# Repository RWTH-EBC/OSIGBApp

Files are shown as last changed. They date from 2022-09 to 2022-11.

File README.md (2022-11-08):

# OSIGBApp
Open-Source Internet of Things (IoT) Gateways for Building Automation Applications

This repository will be populated in course of a journal publication (see publications section down below).

<!-- openocd -f board/esp32-wrover-kit-3.3v.cfg -->

## General

The IoT gateways are designed to operate as an interface for legacy components in building automation systems and IoT-based applications, e. g. connecting to cloud services via IoT protocols communication like MQTT. 

To this end, this repository contains the relevant [schematics and PCB design](https://github.com/RWTH-EBC/OSIGBApp/tree/main/Schematics) to obtain the interfacing hardware allowing to digitize and convert signals from sensors or to actuators. 
Here, the following signals are supported:
- Analog communication (0-10 V, 0-20 mA)
- Resistive measurements of passive RTD-probes (2,3,4-wire)
- Digital communication via RS-485/EIA-485 (for instance used in serial Modbus RTU or BACnet MS/TP communication)

Core component of the gateways is the ESP32 microcontroller.
Hence, the firmware was developed using the Espressif IoT Development Framework [ESP-IDF](https://github.com/espressif/esp-idf), which is the official development framework provided by the manufacturer for the [ESP32](https://espressif.com/en/products/hardware/esp32/overview) chip.
Accordingly, the developed [firmware](https://github.com/RWTH-EBC/OSIGBApp/tree/main/Firmware) is provided as well in this repository. 
In order to ease use and operation of the gateways, we further provide a [documentation](https://github.com/RWTH-EBC/OSIGBApp/tree/main/Documentation). 
Finally, a [performance analysis](https://github.com/RWTH-EBC/OSIGBApp/tree/main/PerformanceAnalysis) has been conducted comparing the measurement performance with a conversion via a PLC.

## Documentation:
- The user Manual "how to operate the gateways" can be found [here](Documentation/manual.pdf). 
- For using the software, [ESP-IDF](https://github.com/espressif/esp-idf) is needed. We also recommend to use [VScode](https://code.visualstudio.com/) with the ESP-IDF extension for programming.
- Furthermore, tips for using the Menuconfig with this software can be found in the Wiki of the repository.
- All functions in the code are commented and a documentation is generated with [Doxygen](https://github.com/doxygen/doxygen). The result can be found in the [DOC folder](https://github.com/RWTH-EBC/OSIGBApp/tree/main/Firmware/doc). You have to clone the repository and open doc/doxygen/html/index.html to view the complete documentation.

- Documentation on how to build the Aio Configurator webpage can be found here: [AIO Configurator](Firmware/doc/aio_configurator.md)
  - The IoT-AIO Configurator is a web page that uses HTML forms to configure the IoT Wireless Adapter.
    The source code and documentation can be obtained here:
      - [Configurator Request](Firmware/doc/markdown/aio_configurator_request.html)
      - [Configurator Response](Firmware/doc/markdown/aio_configurator_response.html)
     
- Further developement Ideas, by Carlo Guarnieri can be found here: [Developments](Firmware/doc/developments.md)

## Terms of use
All content provided in this repository is released under the [MIT License](https://github.com/RWTH-EBC/OSIGBApp/blob/main/LICENSE). 
If any of the content provided is used, please give credit by referencing the related publication, as decribed in the subsequent section.

## Publications and referencing
<!--The IoT-Gateways have been developed in several research projects between 2018 and 2021. A core development for the current state has been conducted during the Master Thesis of Kai Droste in 2020. -->
We kindly ask all publicly disseminated projects employing components of the IoT gateways to cite the following paper:

<!--  - Kai Droste "[Development of a cloud controlled building automation and comparison with the current state of the art](https://git-ce.rwth-aachen.de/ebc/projects/ebc0449_bmwi_nextgenbat_ga/iot-development/iot-development.dissemination/theses/development-of-a-cloud-controlled-building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)", 2020 Masterthesis   -->
- **Schraven, Markus Hans, Kai Droste, Carlo Guarnieri Calò Carducci, Dirk Müller, and Antonello Monti. 2022. "Open-Source Internet of Things Gateways for Building Automation Applications" Journal of Sensor and Actuator Networks 11, no. 4: 74. https://doi.org/10.3390/jsan11040074**

Previous development stages are documented in:
- M.H. Schraven, C. Guarnieri Calò Carducci, M.A. Baranski, D. Mueller, A. Monti, “Designing a Development Board for Research on IoT Appli-cations in Building Automation Systems,” 36th International Symposiumon  Automation  and  Robotics  in  Construction  (ISARC  2019),  Banff,Canada, 2019, pp. 82-90, [DOI: 10.22260/ISARC2019/0012](https://doi.org/10.22260/ISARC2019/0012)
- C. Guarnieri Calò Carducci, A. Monti, M. H. Schraven, M. Schumacher and D. Mueller, “Enabling ESP32-based IoT Applications in Building Automation Systems,” 2019 II Workshop on Metrology for Industry 4.0 and IoT (MetroInd4.0&IoT), Naples, Italy, 2019, pp. 306-311, [DOI: 10.1109/METROI4.2019.8792852](https://doi.org/10.1109/METROI4.2019.8792852)

# Further software related to IoT-AIO

## IoT-AIO Configurator

# Contact
EONERC EBC Logo (http://www.ebc.eonerc.rwth-aachen.de)

- [Kai Droste](mailto:kai.droste@eonerc.rwth-aachen.de)
- [Markus Schraven](mailto:mschrave@eonerc.rwth-aachen.de)
- [Carlo Guarnieri](mailto:cguarnieri@eonerc.rwth-aachen.de)

[EON Energy Research Center (EONERC)](http://www.eonerc.rwth-aachen.de)  
[Institute for Automation of Complex Power Systems (ACS)](http://www.acs.eonerc.rwth-aachen.de)  
[RWTH University Aachen, Germany](http://www.rwth-aachen.de)

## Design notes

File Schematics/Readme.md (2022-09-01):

# Schematics

This folder contains the schematics of the three gateways. The schematics are drawn with the Open-Source software KiCAD.

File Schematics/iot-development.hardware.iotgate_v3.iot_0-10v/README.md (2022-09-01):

# iot analog io interface

This repository entails the specifications and PCB design of a gateway communicating with 0-10 V and 0-20 mA devices. 

**Specifications:**
*  Case:
    * [Datasheet](Datasheet/M-2K-12_V1.pdf)
    * outer dimensions: 85 x 85 x 37 mm 
    * inner dimensions: 73 x 73 x 25 mm
    * [PCB-Measurements:](Datasheet/Junction-Box-PCB.pdf) 75 x 40 x 1.6 mm 
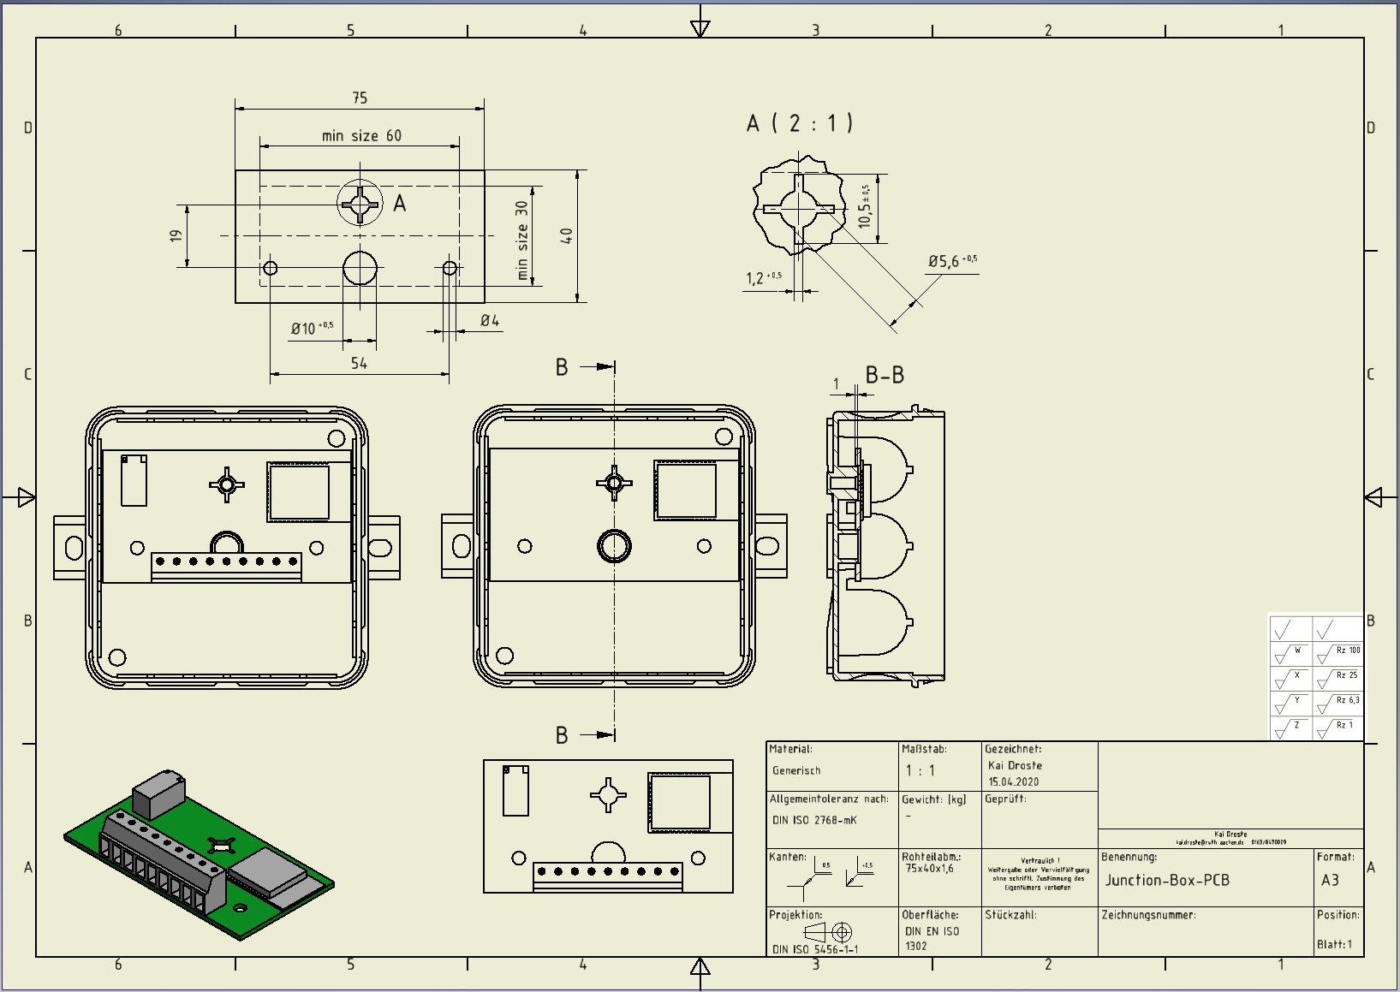
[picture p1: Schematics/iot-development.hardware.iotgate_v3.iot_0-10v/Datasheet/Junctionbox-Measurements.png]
    

*  Components: 
    * ESP32-WROOM-32D(4MB)
    * Header Pins for flashing bridge [ESP-Prog](https://github.com/espressif/esp-iot-solution/blob/master/documents/evaluation_boards/ESP-Prog_guide_en.md)
    * Reset Button (EN)
    * Status / Debugging LED
    * DC-DC Buck Converter: VXO7805-500-M-TR [Mouser-Link](https://eu.mouser.com/ProductDetail/CUI-Inc/VXO7805-500-M-TR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)  
    * LDO 5V-3.3V: REG1117-3.3/2K5 [Mouser-Link](https://eu.mouser.com/ProductDetail/Texas-Instruments/REG1117-33-2K5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)
       
    * ADC/DAC as external circuit 
        * ADC
            * 0-10 V
            * resolution 10 bit 
    * XTR111 Voltage to current Converter [Mouser-Link](https://www.mouser.de/ProductDetail/Texas-Instruments/XTR111AIDGQR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)
    * header with jumper to set current or voltage mode
*  Additional components:
    * Double relay switch
    * Connector: 9 Position Screw Terminal 
        * [TB001-500-09BE](https://www.mouser.de/ProductDetailCUI-Devices/TB001-500-09BEqs=sGAEpiMZZMvPvGwLNS671%2FDanv8Jav06pFwBruE7rNiHV5dcUdCoOg%3D3D)
        * [Datasheet](Datasheet/tb001-500-1550615.pdf)
    * 2x6 pin header: M20-9760346 [Mouser-Link](https://eu.mouser.com/ProductDetail/Harwin/M20-9760346?qs=sGAEpiMZZMs%252BGHln7q6pmzlZUuX%2F53qjFNOh3aK0cf8%3D)

*  IOs:
1. 24 VDC (input, supply gateway)
2. GND (input, supply gateway)
3. 24 VDC (output, supply sensor/actuator device)
4. GND (output, sensor/actuator device)
5. 0-10 VDC / 0-20 mA (switched by jumper) (feedback signal from sensor/actuator device)
6. 0-10 VDC / 0-20 mA (switched by jumper) (feedback signal from sensor/actuator device forwarding to PLC)
7. 0-10 VDC / 0-20 mA (switched by jumper) (set point signal to sensor/actuator device forwarding from PLC)
8. 0-10 VDC / 0-20 mA (switched by jumper) (set point signal to sensor/actuator device)
9. 24 VDC (input for relay switch from PLC)

## TODO:
- [x] Housing
	- [x] Measurements
	- [x] Mounting Holes

## Example board layout:

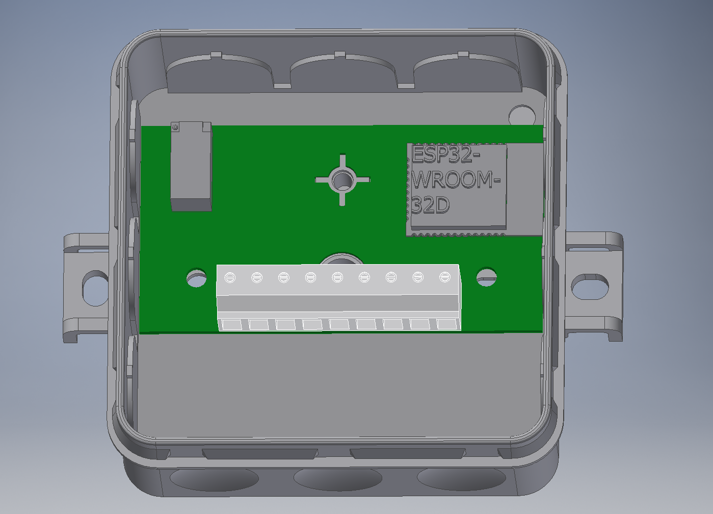
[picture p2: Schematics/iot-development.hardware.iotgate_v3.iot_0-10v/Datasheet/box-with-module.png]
box with module

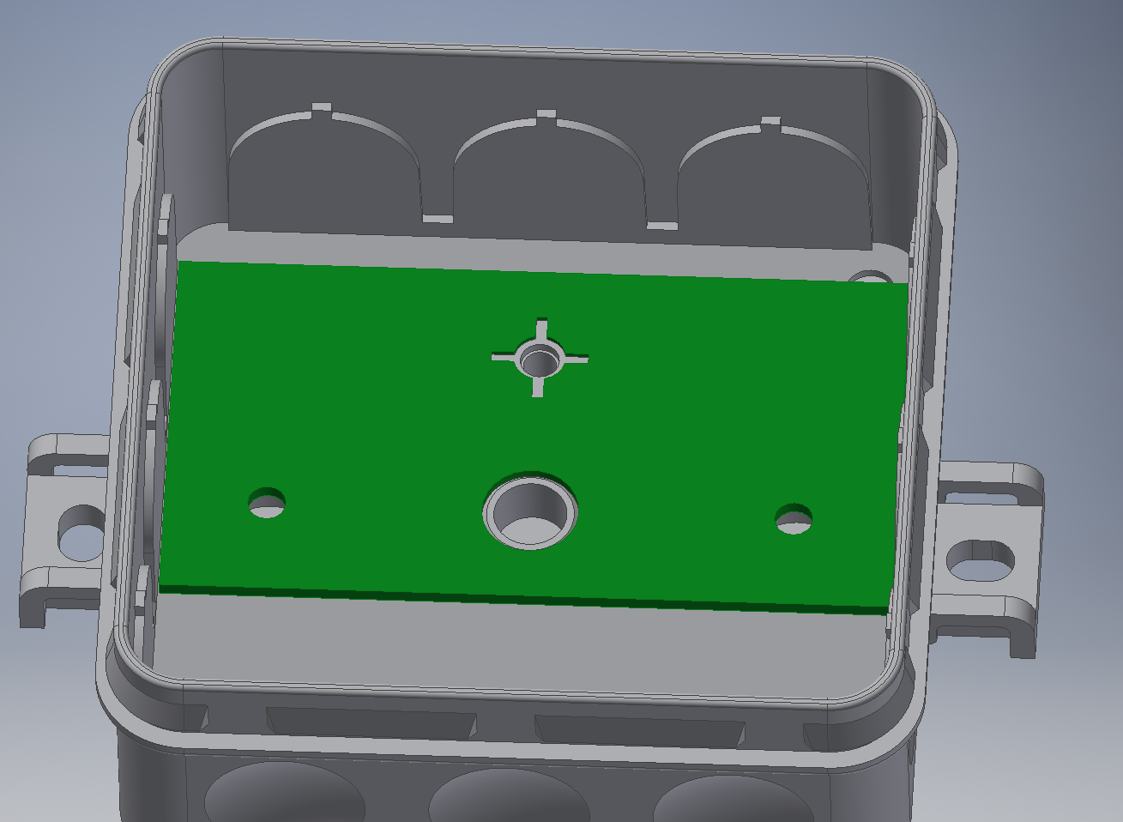
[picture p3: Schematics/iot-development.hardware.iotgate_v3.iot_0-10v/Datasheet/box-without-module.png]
box without module


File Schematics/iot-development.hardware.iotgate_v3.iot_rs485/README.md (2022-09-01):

# iot_rs485

This repository entails the specifications and PCB design of a gateway communicating with devices via Modbus RTU or BACnet MS/TP.

**Specifications:**
*  Battery: None
*  Case:
    * [Datasheet](Datasheet/M-2K-12_V1.pdf)
    * outer dimensions: 85 x 85 x 37 mm 
    * inner dimensions: 73 x 73 x 25 mm
    * [PCB-Measurements:](Datasheet/Junction-Box-PCB.pdf) 75 x 40 x 1.6 mm 
    

*  Components: 
    * ESP32-WROOM-32D(16MB)
    * Header Pins for flashing bridge [ESP-Prog](https://github.com/espressif/esp-iot-solution/blob/master/documents/evaluation_boards/ESP-Prog_guide_en.md)
    * UART TTL to RS485 converter (Maybe BACnet needs an own gateway with a card reader? Needs to be tested)
        * Modbus-RTU
        * BACnet MS/TP
*  Additional components:
    * Double relay switch
    * Connector: 9 Position Screw Terminal 
        * [TB001-500-09BE](https://www.mouser.de/ProductDetail/CUI-Devices/TB001-500-09BE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)
        * [Datasheet](Datasheet/tb001-500-1550615.pdf)

*  IOs:
1. 24 VDC (input, supply gateway)
2. GND (input, supply gateway)
3. 24 VDC (output, supply sensor/actuator device)
4. GND (output, supply sensor/actuator device)
5. M+ (Bus signal from sensor/actuator device)
6. M- (Bus signal from sensor/actuator device)
7. M+ (Bus signal to sensor/actuator device forwarding from PLC)
8. M- (Bus signal to sensor/actuator device forwarding from PLC)
9. 24 VDC (input for relay switch from PLC)

## TODO:

- [ ] Testing BACnet.

## Example board layout:

box with module
box without module

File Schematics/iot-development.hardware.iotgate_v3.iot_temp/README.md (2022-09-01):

# iot_temp

This repository entails the specifications and PCB design of a gateway communicating with temperature sensors.

**Specifications:**
*  Battery: LiFePo4 18650 cell [lipopower.de](https://shop.lipopower.de/A123-Systems-APR18650M1A-1100mAh)
    * Battery holder: [Datasheet](Datasheet/Keystone_01142020_1042.pdf)
*  Case dimensions: 120 x 75 x 36 mm 
    *  Case Datasheet: [Spelsberg 2K-16](Datasheet/M-346-916-01_V1.pdf)
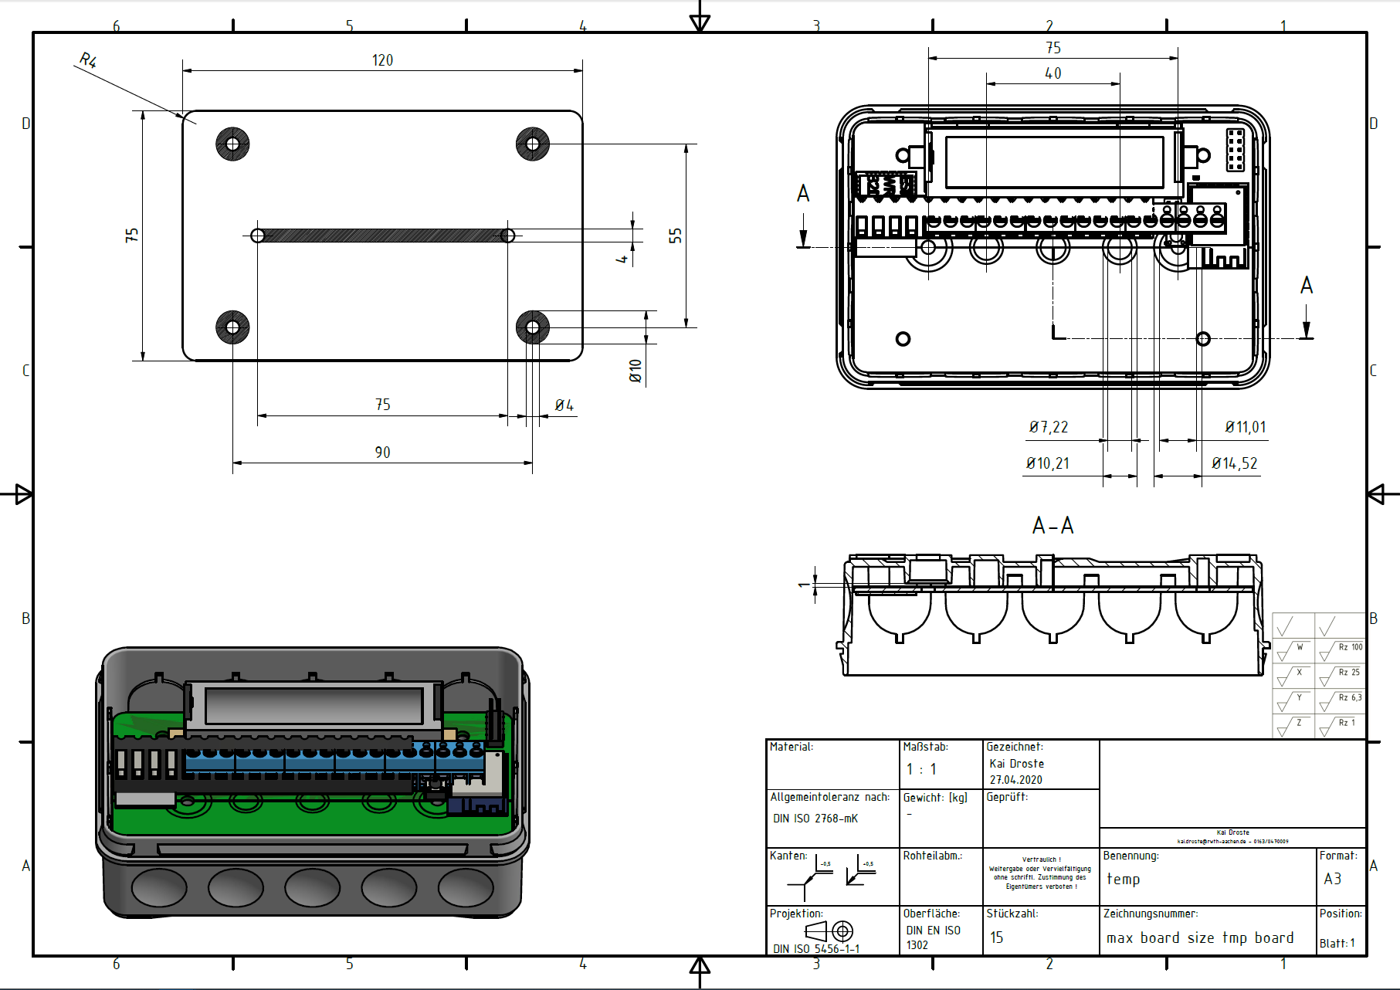
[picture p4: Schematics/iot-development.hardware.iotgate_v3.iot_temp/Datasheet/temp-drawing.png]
Temp-drawing

[Drawing](Datasheet\temp-drawing.pdf)

* ESP32-WROOM-32D
* Header Pins for flashing bridge 
    * [ESP-Prog](https://github.comespressif/esp-iot-solution/blob/master/documentsevaluation_boards/ESP-Prog_guide_en.md)
* Reset Button (EN)
* 2x MAX31865 for 2 RTD-Elements
* TS3A44159PWR Multiplexer for switching between PLC and ESP32
    * [Mouser-Link](https://www.mouser.de/ProductDetail/Texas-Instruments/TS3A44159PWR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)
* Terminal block 18 TB004-508-18BE 
    * [Mouser-Link](https://www.mouser.de/ProductDetail/CUI-Devices/TB004-508-18BE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)

**IOs:**
1. Lead 1 RTD 1 (from RTD to Gateway) 
2. Lead 2 RTD 1 (from RTD to Gateway)
3. Lead 3 RTD 1 (from RTD to Gateway)
4. Lead 4 RTD 1 (from RTD to Gateway)
5. Lead 1 RTD 2 (from RTD to Gateway)
6. Lead 2 RTD 2 (from RTD to Gateway)
7. Lead 3 RTD 2 (from RTD to Gateway)
8. Lead 4 RTD 2 (from RTD to Gateway)
9. Lead 1 RTD 1 (from RTD forwarding to PLC) 
10. Lead 2 RTD 1 (from RTD forwarding to PLC)
11. Lead 3 RTD 1 (from RTD forwarding to PLC)
12. Lead 4 RTD 1 (from RTD forwarding to PLC)
13. Lead 1 RTD 2 (from RTD forwarding to PLC)
14. Lead 2 RTD 2 (from RTD forwarding to PLC)
15. Lead 3 RTD 2 (from RTD forwarding to PLC)
16. Lead 4 RTD 2 (from RTD forwarding to PLC)
17. GND (input for relais switch from PLC)
18. 24 VDC (input for relais switch from PLC)

## TODO:
- [x] Housing for Battery and Board
	- [x] Measurements
	- [x] Mounting Holes

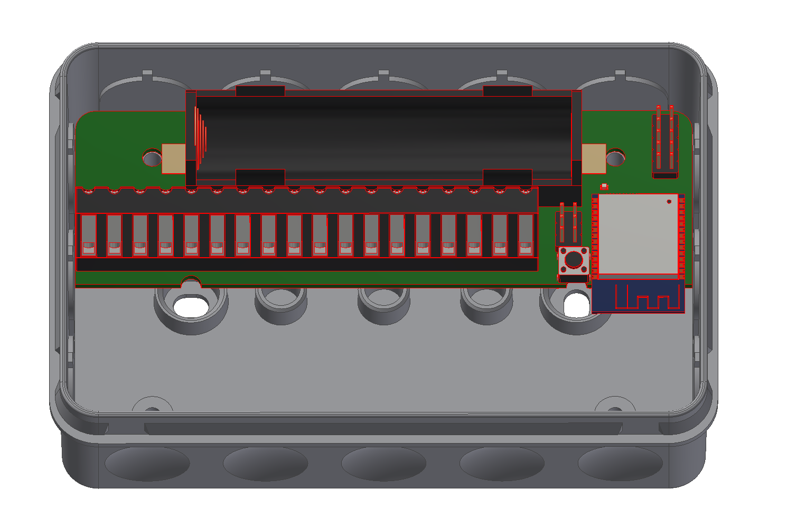
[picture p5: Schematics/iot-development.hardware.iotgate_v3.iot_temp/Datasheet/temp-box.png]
Rendering


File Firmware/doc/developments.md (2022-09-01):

# Possible developments

- DNS Captive Portal feature for autoloading the configurator page upon new connection
    - [DNSServer [Arduino-ESP32]](https://github.com/espressif/arduino-esp32/blob/master/libraries/DNSServer/examples/CaptivePortal/CaptivePortal.ino)
    - [mDNS [ESP-IDF]](https://github.com/espressif/esp-idf/tree/master/examples/protocols/mdns)

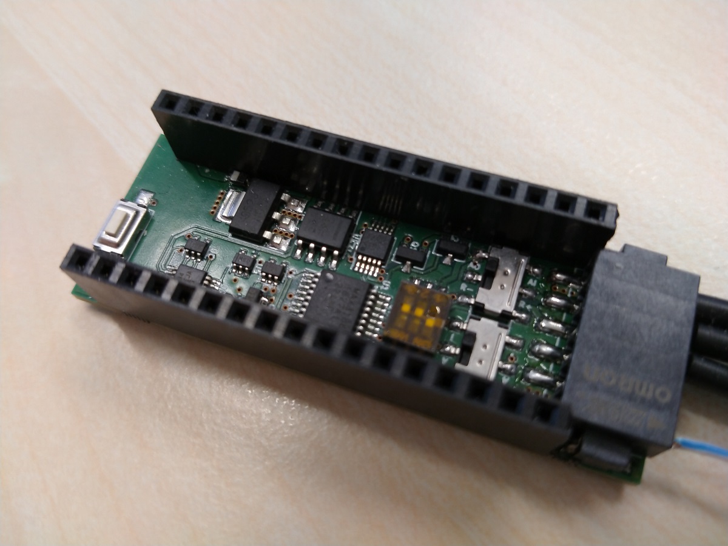
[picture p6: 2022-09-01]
Firmware/assets/image.jpg

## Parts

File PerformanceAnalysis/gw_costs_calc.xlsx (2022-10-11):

Gateway costs
 | Analog |  | Digital |  | Temperature
PCB Manufacturing | 223.25 € | 3.92 € | 182.02 € | 4.79 € | 244.86 € | 11.13 €
Assembly | 663.48 € | 11.64 € | 396.34 € | 10.43 € | 378.84 € | 17.22 €
Components | 1169.07 € | 20.51 € | 625.10 € | 16.45 € | 549.34 € | 24.97 €
Summe | 2055.80 € | 36.07 € | 1203.46 € | 31.67 € | 1173.04 € | 53.32 €
Anzahl | 57 |  | 38 |  | 22

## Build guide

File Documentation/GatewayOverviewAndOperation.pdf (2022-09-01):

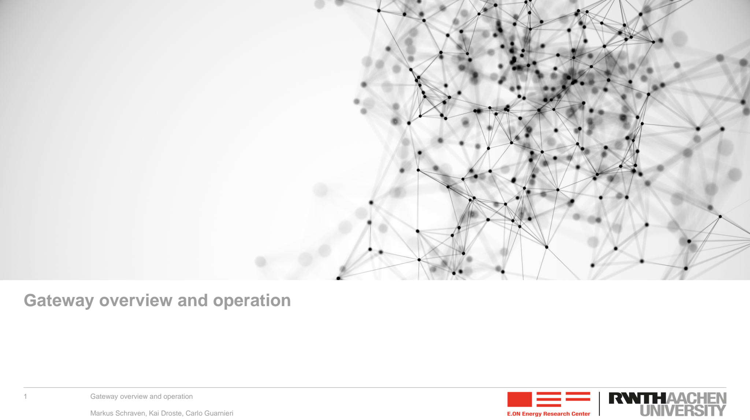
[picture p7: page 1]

Gateway overview and operation

Markus Schraven, Kai Droste, Carlo Guarnieri

## Gateway overview and operation

### Content

### ■ 1. General information, gateway properties and possible use-cases

### ■ 2. Operators instructions I – Configuration

### ■ 3. Operators instructions II – Inital setup / Flashing the firmware

### ■ 4. Developers instructions – Development / Adjusting the firmware

# General information

### Microcontroller

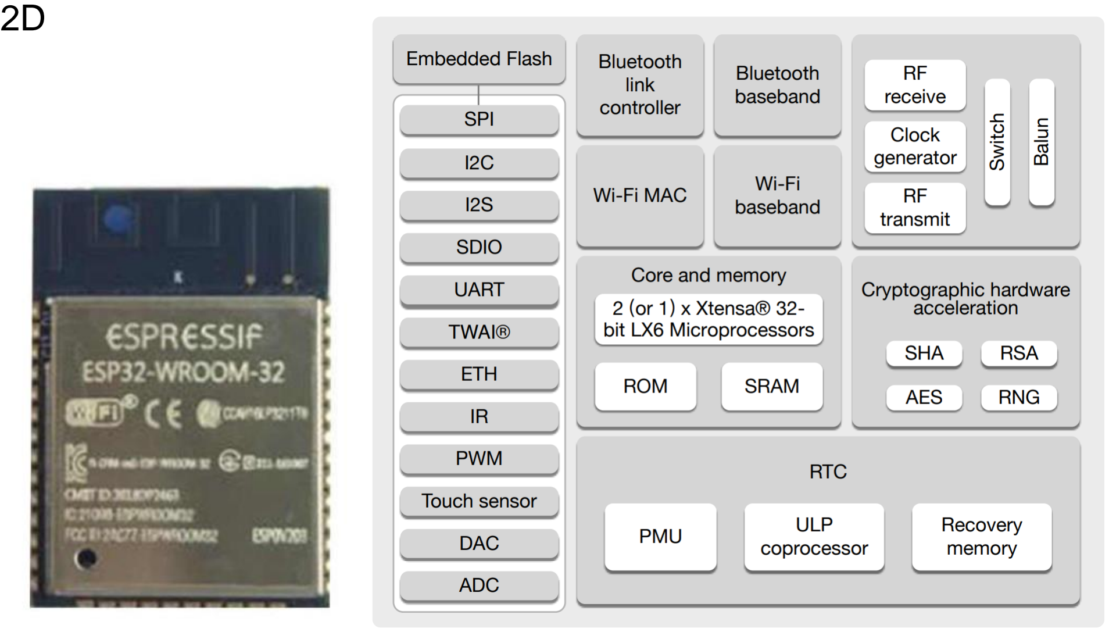
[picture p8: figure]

■ Core component is an ESP32-WROOM32D

≡ 32-bit, dual-core 40 MHz
≡ 16MB flash storage
≡ 34 programmable GPIOS
≡ 2,4 GHz WiFi
≡ Bluetooth, Bluetooth low energy ■ Programming languages

≡ C (ESP-IDF)
≡ C++ (Arduino IDE)
≡ Micropython

Data sheet: https://www.espressif.com/sites/default/files/documentation/esp32-wroom-32d_esp32-wroom-32u_datasheet_en.pdf

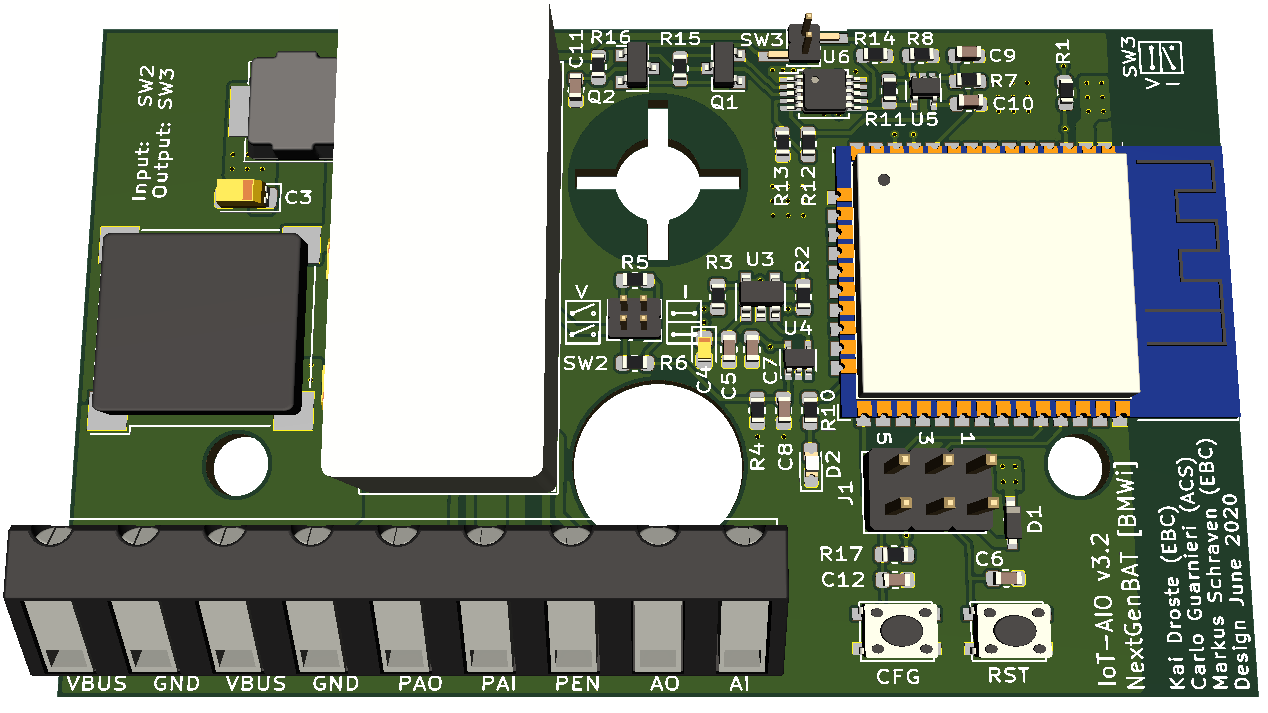
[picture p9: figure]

Analog
■ 0(2) – 10 V
■ 0(4) – 20 mA

■ 1x Input, 1x Output
(single-ended)
■ MCP3021, XTR111

Temperature
■ RTD-probe

≡ 2,3,4 wires
■ Optional Battery operated (LiFePO4, 18650 cells)
■ 24 VDC add-on supply
■ 2 RTD-probes
■ MAX31865

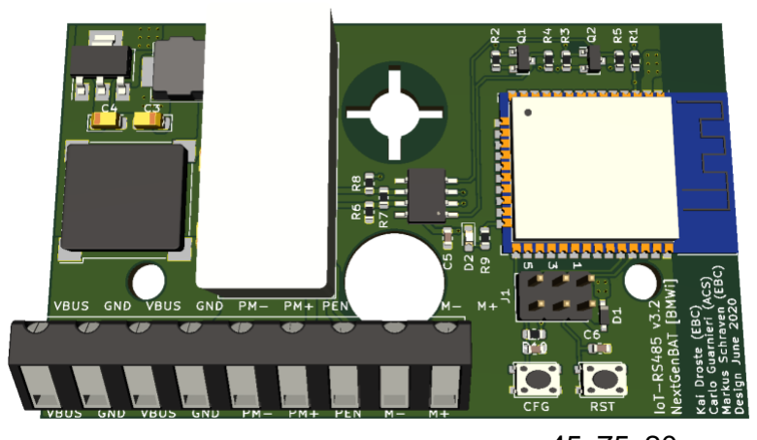
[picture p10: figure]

Digital
■ RS485
■ Modbus RTU
■ (BACnet MS/TP, not
yet implemented)
■ Communication with one
field device (Software)
■ MAX13487
Price: 36,07 €/pcs. | 31,67 €/pcs. | 53,32 €/pcs.

45x120x17 mm
45x75x20 mm | 45x75x20 mm

### Analog Gateway

■ Relay
■ Switching between
internal and external
signal path (“to PLC”),
compare slide 16

Pins labeled with „Not in use“ are used for the switching mechanism. More details can be found in chapter 2 of the instruction manual or slide 16 in this presentation.

### Digital Gateway

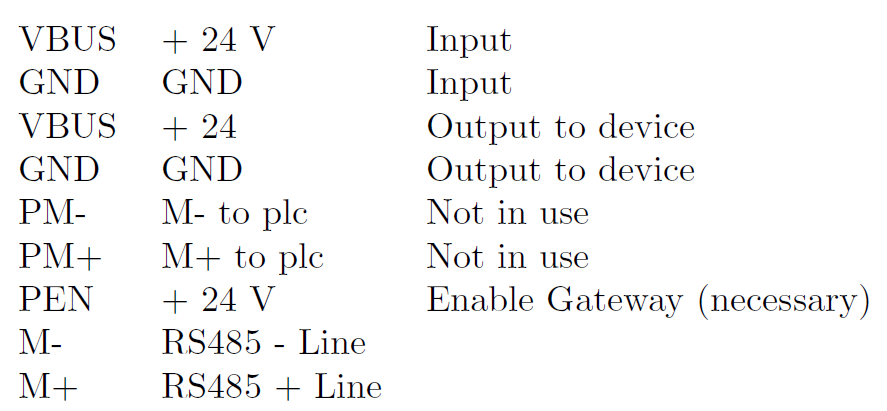
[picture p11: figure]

Pins labeled with „Not in use“ are used for the switching mechanism. More details can be found in chapter 2 of the instruction manual or slide 16 in this presentation.

### Temperature Gateway

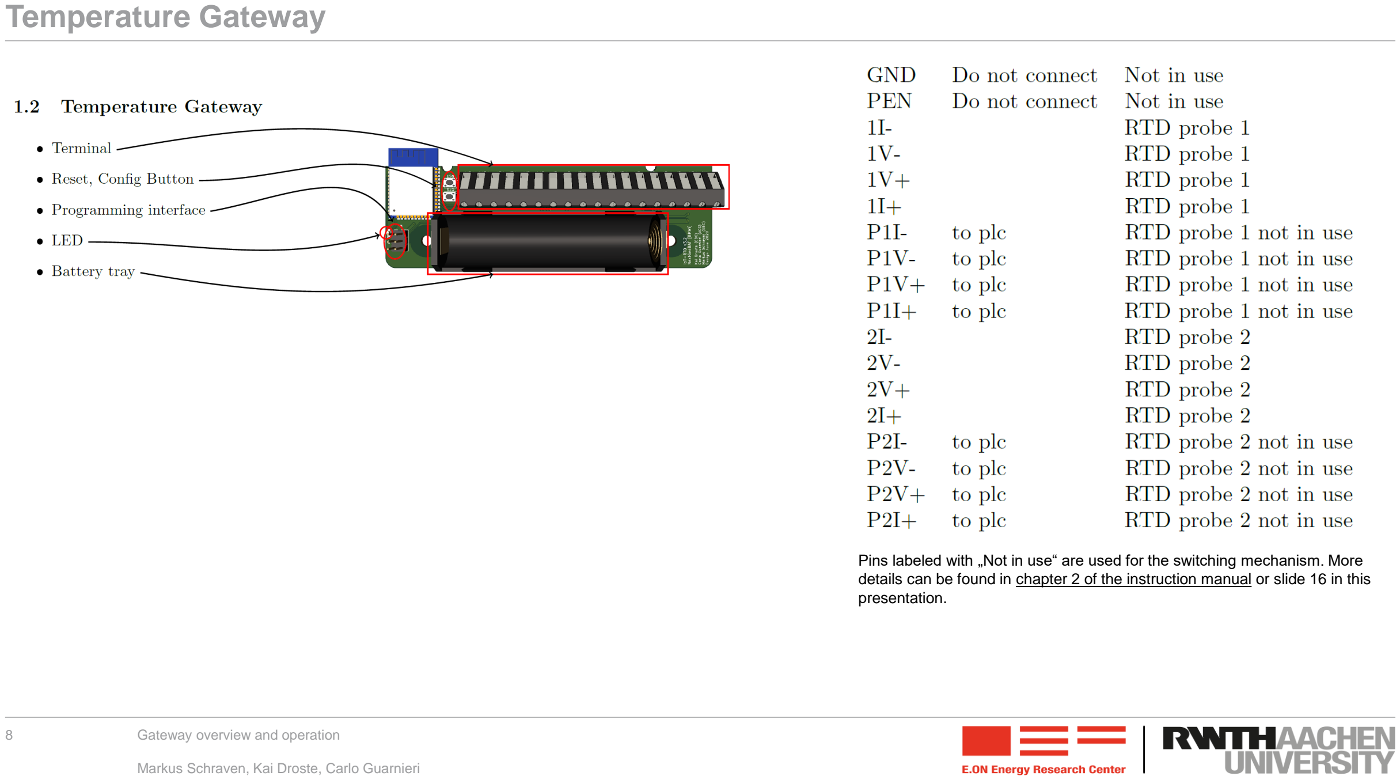
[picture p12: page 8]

Pins labeled with „Not in use“ are used for the switching mechanism. More details can be found in chapter 2 of the instruction manual or slide 16 in this presentation.

### Configuration interface

■ Web server is accessed via the IP address of the gateway, see slide 13

≡ The IP address can be discovered using a BLE beacon ■ Configuration exclusively via web server

■ https://github.com/RWTH-

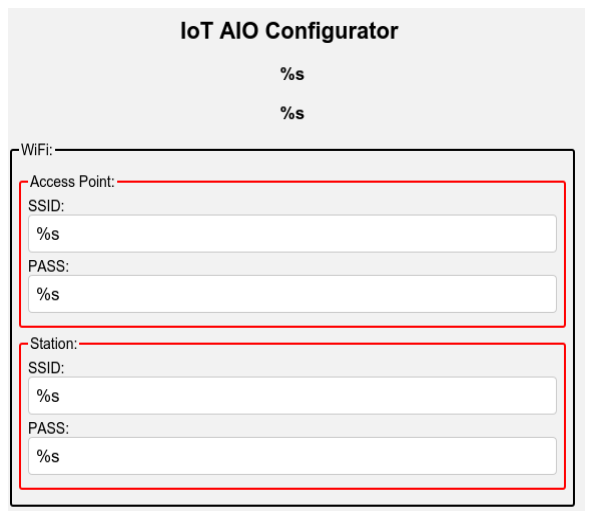
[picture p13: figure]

EBC/OSIGBApp/blob/main/Firmware/doc/aio_config urator_request.html

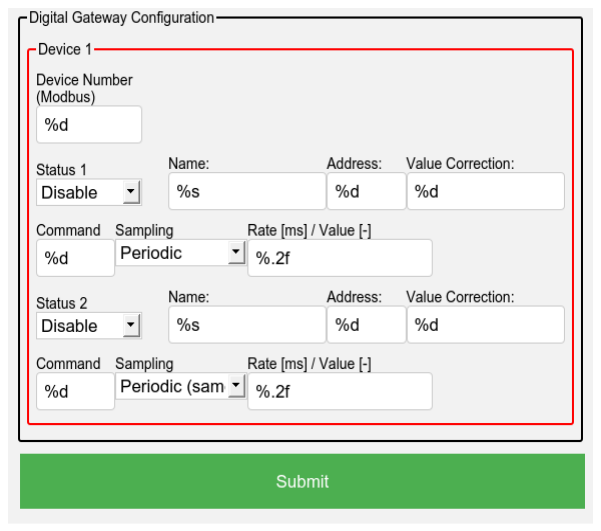
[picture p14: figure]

### Example application

### Further available information and repositories

■ Firmware (Programmed in C using ESP-IDF)

≡ OSIGBApp/Firmware at main · RWTH-EBC/OSIGBApp (github.com) (https://github.com/RWTH-EBC/OSIGBApp/tree/main/Firmware) ■ Hardware (PCB design in KiCAD)

≡ OSIGBApp/Schematics at main · RWTH-EBC/OSIGBApp (github.com) (https://github.com/RWTH-EBC/OSIGBApp/tree/main/Schematics) ■ Instructions manual

≡ OSIGBApp/Documentation at main · RWTH-EBC/OSIGBApp (github.com) (https://github.com/RWTH-EBC/OSIGBApp/tree/main/Documentation)

# Operators instructions I - Configuration

### Accessing the web server interface

■ Requirements: Firmware is already flashed, see operators instructions II (slides 26 onwards)

■ In delivery state, the gateway is not able to connect to a WiFi network, directly

≡ First, the CFG button has to be pressed between 1 s and 3 s to initialize the access point interface = The AP will be displayed as ESPxxxx in the available WiFi connections (AP mode)

□ The gateway sets up an individual network. The default password is 123456789
= Connect to the WiFi AP with an end device of your choice (e. g. computer, smartphone, etc.)
= The web server interface can be accessed with a web browser and the IP address 192.168.4.1

■ When already connected to a WiFi network

≡ The web interface is now accessed via the IP of the gateway
≡ For finding the IP, you can, for instance:
= Use BLE beacon => Press CFG button for < 1 s: LED blinks 2x
□ The IP address is provided as BLE-Beacon, which can be received with a Bluetooth-enabled device. e. g.:
- Bluetooth Beacon Interactor (Windows Store)
- eBeacon (IOS)
= Alternatively, checking IP in router config (might be incomprehensible with many gateways in the network)

### WiFi configuration

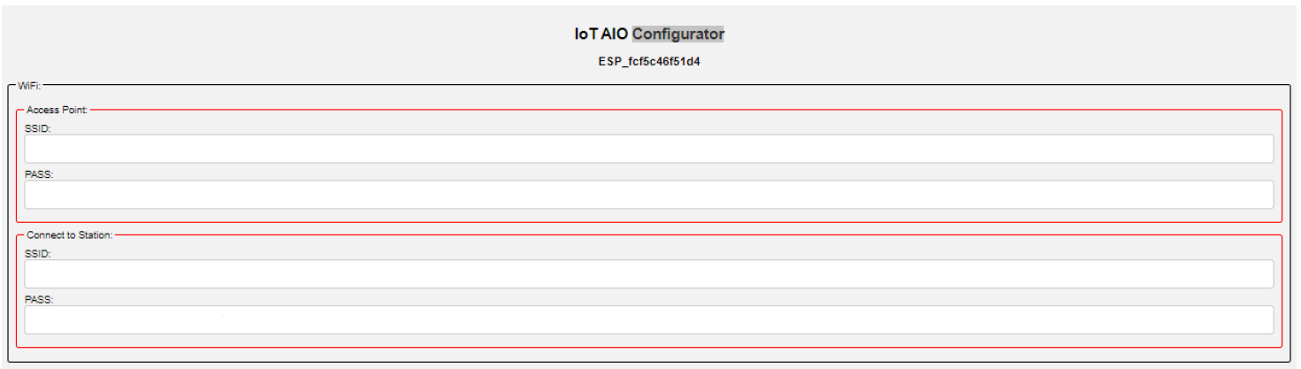
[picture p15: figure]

■ Access Point

≡ Set name and password for the AP of the Gateway (e. g. credentials when activating the AP configuration)
≡ Should usually not be touched, as the gateway will most likely be operated connected to a network. Default credentials are SSID=MAC address of the ESP, and PW=12345679
■ Station

≡ SSID and password of the WiFi network the Gateway should be connected to.
= Note that it might not be possible to connect with special encrypted networks like WPA2 enterprise (Eduroam)

### MQTT configuration

■ Supports JSON and special encoding for aedifion and FIWARE platform ■ A detailled manual is located in this same repository:

≡ OSIGBApp/Documentation at main · RWTH-EBC/OSIGBApp (github.com) (https://github.com/RWTH-EBC/OSIGBApp/tree/main/Documentation)

### Switching between SotA and IoT mode

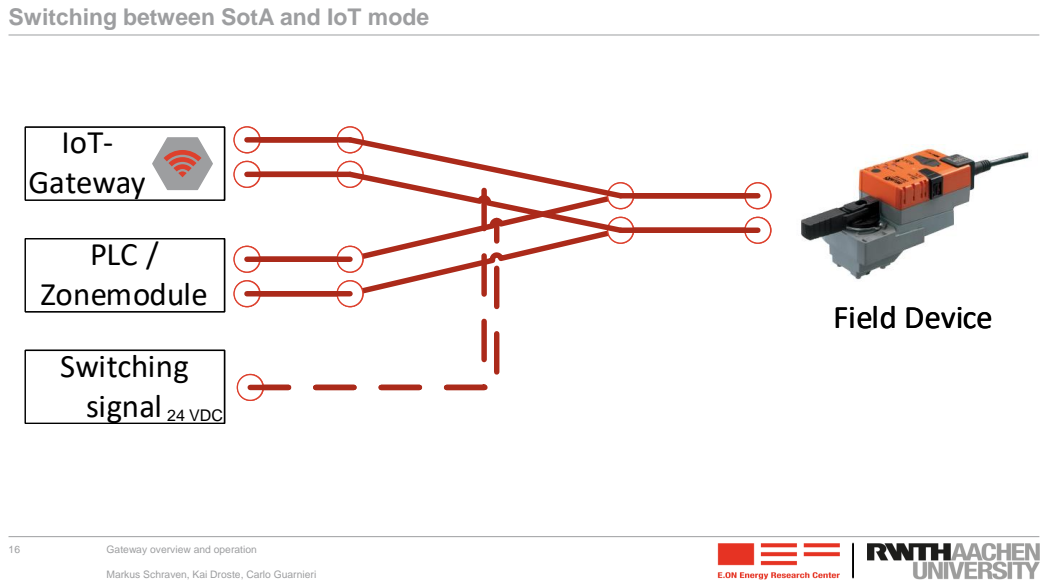
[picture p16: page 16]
IoT- Gateway; PLC / Zonemodule; Field Device; Switching signal; 24 VDC

### Switching between SotA and IoT mode: Special considerations

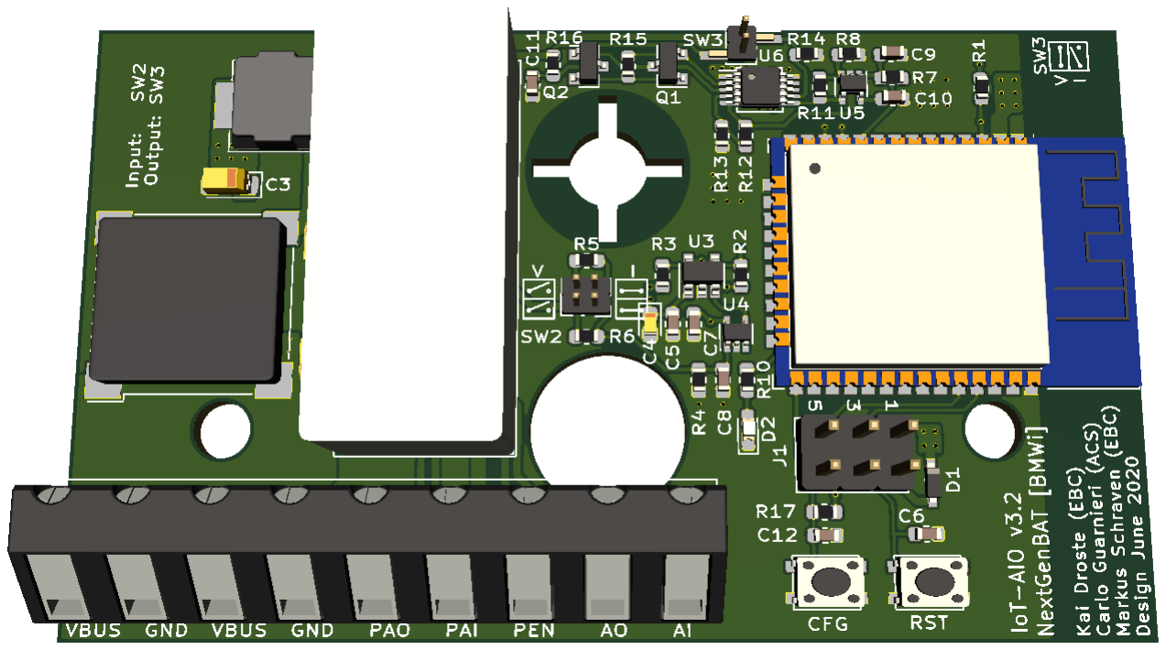
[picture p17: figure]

■ Analog / Digital Gateway

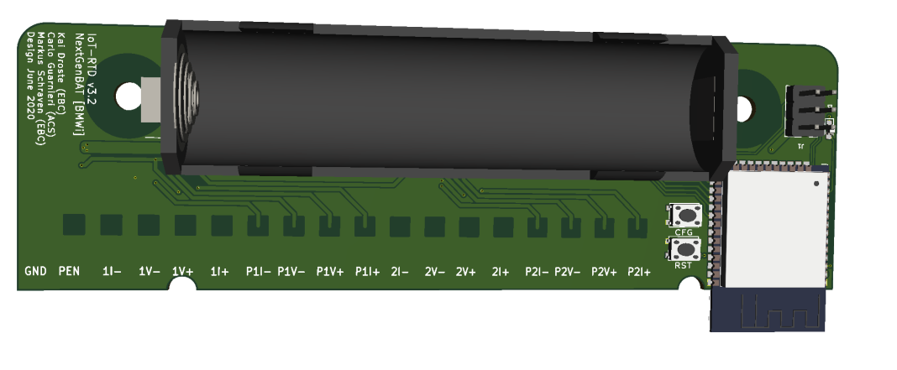
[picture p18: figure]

≡ If PEN = GND → AO, AI are connected to PAO und PAI (hence, no internal processing by the Gateway)
≡ Switching is achieved via 24 VDC signal on PEN terminal, e. g. with a jumper to VBUS, compare slide 6 onwards ≡ Switching relais(RT424024): DDEController (te.com) (https://www.te.com/commerce/DocumentDelivery/DDEController?Action=showdoc)
■ Temperature Gateway

≡ GND and PEN (24 VDC) must be connected for an internal processing, without the 24 VDC signal on PEN, the input terminals (I+-,V+-) are directly connected with the output terminals (PI+-,PV+-).
≡ Switching multiplexer(TS3A44159): TS3A44159 0.45-Ω Quad SPDT Analog Switch 4-Channel 2:1 Multiplexer – Demultiplexer With Two Controls datasheet (Rev. B) (https://www.ti.com/lit/ds/symlink/ts3a44159.pdf?ts=1587831159497)
≡ The Gateway requires a permanent power supply even if signals are only forwarded to the external system!

### Hardware configuration: Analog Gateway - Switching voltage and current signal mode

■ 3x2 pin header jumper required

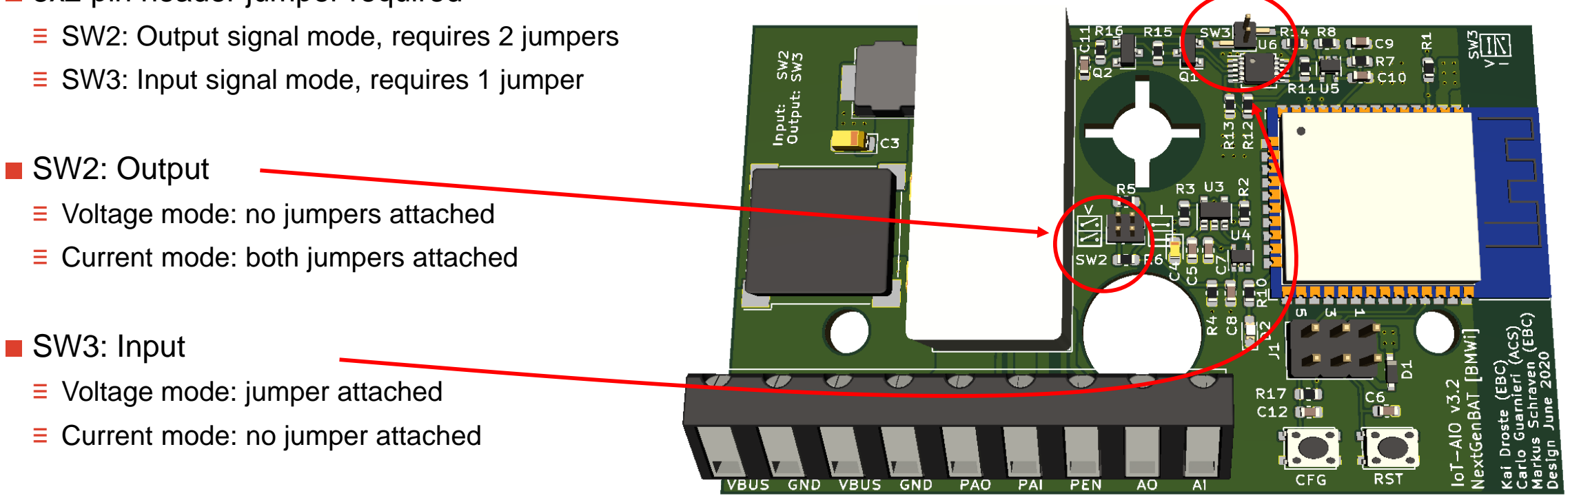
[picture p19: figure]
■ SW2: Output; ≡ Voltage mode: no jumpers attached; ≡ Current mode: both jumpers attached; ■ SW3: Input; ≡ Voltage mode: jumper attached; ≡ Current mode: no jumper attached

≡ SW2: Output signal mode, requires 2 jumpers
≡ SW3: Input signal mode, requires 1 jumper

### Hardware configuration: Temperature GW I - Connecting the RTD element

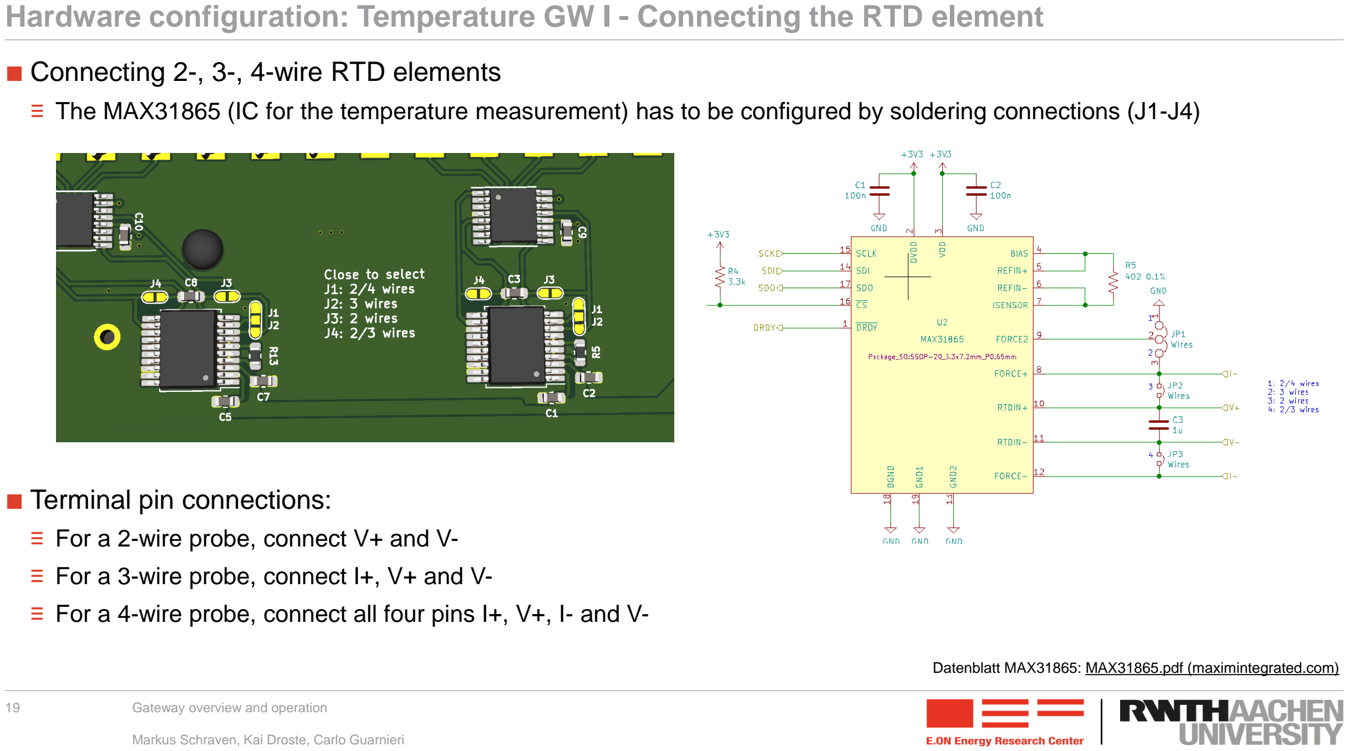
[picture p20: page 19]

■ Connecting 2-, 3-, 4-wire RTD elements

≡ The MAX31865 (IC for the temperature measurement) has to be configured by soldering connections (J1-J4)

■ Terminal pin connections:

≡ For a 2-wire probe, connect V+ and V-
≡ For a 3-wire probe, connect I+, V+ and V-
≡ For a 4-wire probe, connect all four pins I+, V+, I- and V-

Datenblatt MAX31865: MAX31865.pdf (maximintegrated.com) (https://datasheets.maximintegrated.com/en/ds/MAX31865.pdf)

### Hardware configuration: Temperature GW II - Adjusting the RTD type/reference resistor

■ In order to connect a different type than a PT100 probe, e. g. a PT1000, the reference resistors R13 for channel 1 and R5 for channel 2 (see slide 19) have to be exchanged (soldering required).

≡ The resistor should amount to 4 time the nominal value, e. g.
= PT100 requires a 400 Ω resistor
= PT1000 requires a 4 kΩ resistor

≡ Additionally, in the configuration (web interface), the type/reference needs to be adjusted
= PT1000 is implemented as additional choice in the drop-down menu, different resistors require software adjustments

Datenblatt MAX31865: MAX31865.pdf (maximintegrated.com) (https://datasheets.maximintegrated.com/en/ds/MAX31865.pdf)

### Hardware configuration: Temperature GW III - 24 VDC power supply

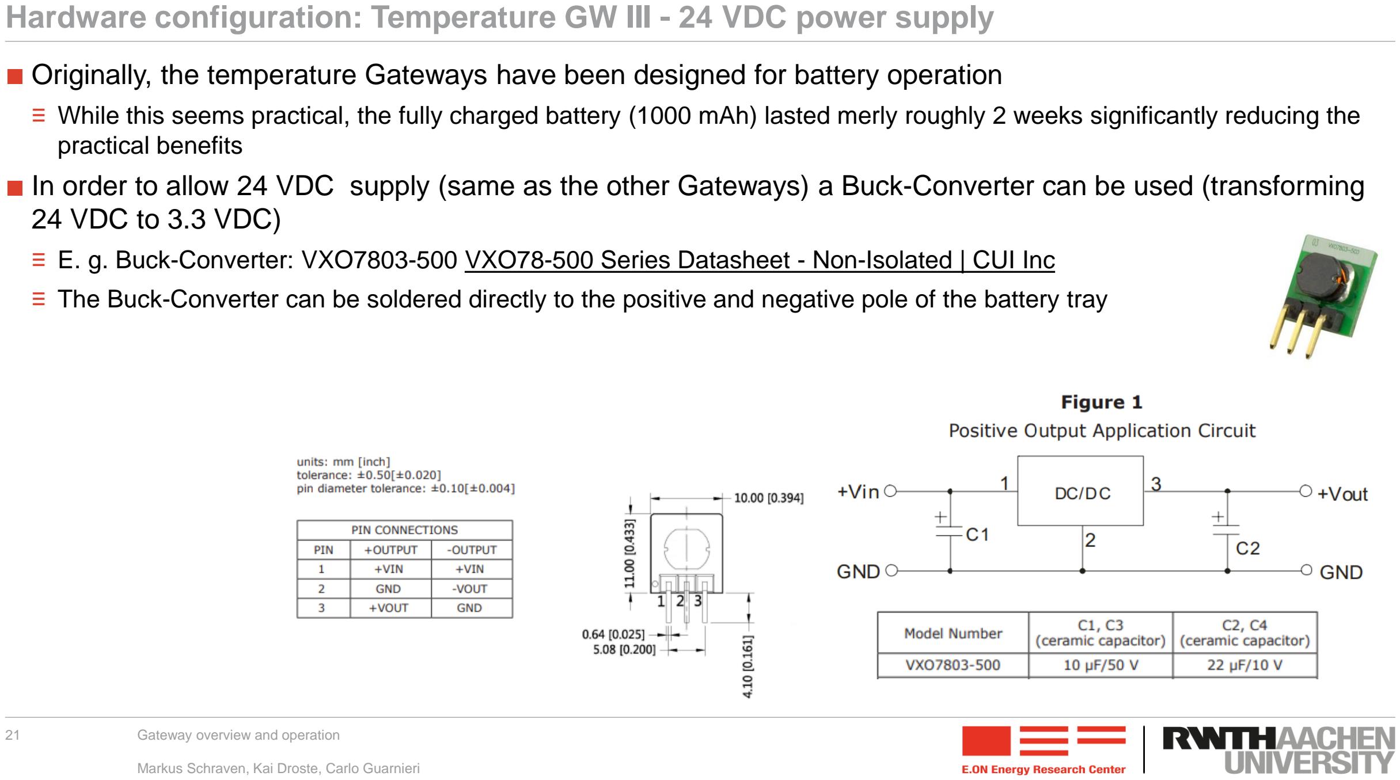
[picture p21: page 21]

■ Originally, the temperature Gateways have been designed for battery operation

≡ While this seems practical, the fully charged battery (1000 mAh) lasted merly roughly 2 weeks significantly reducing the practical benefits
■ In order to allow 24 VDC supply (same as the other Gateways) a Buck-Converter can be used (transforming 24 VDC to 3.3 VDC)
≡ E. g. Buck-Converter: VXO7803-500 VXO78-500 Series Datasheet - Non-Isolated | CUI Inc (https://www.cui.com/product/resource/vxo78-500.pdf)
≡ The Buck-Converter can be soldered directly to the positive and negative pole of the battery tray

### Software configuration: Digital GW I - Configuration of Modbus coils and registers

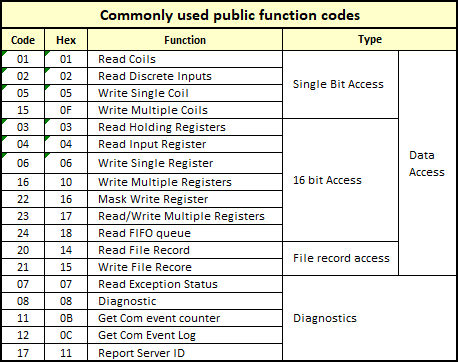
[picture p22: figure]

■ Device Number:

≡ Device ID: Device address within the bus ■ Status (read & write holding registers)

≡ Read
≡ Write
■ Register (function code)

≡ E.g. 3: Read holding register or 6: write single register ≡ See table on the right
■ Address:

≡ Register address to be read or written

■ Typical function codes

### Software configuration: Digital GW II - Configuration of Modbus coils and registers

■ Example Modbus register for a volume flow control actuator ■ Typical function codes

Software configuration: Digital GW III - Configuration of Modbus coils and registers - Example

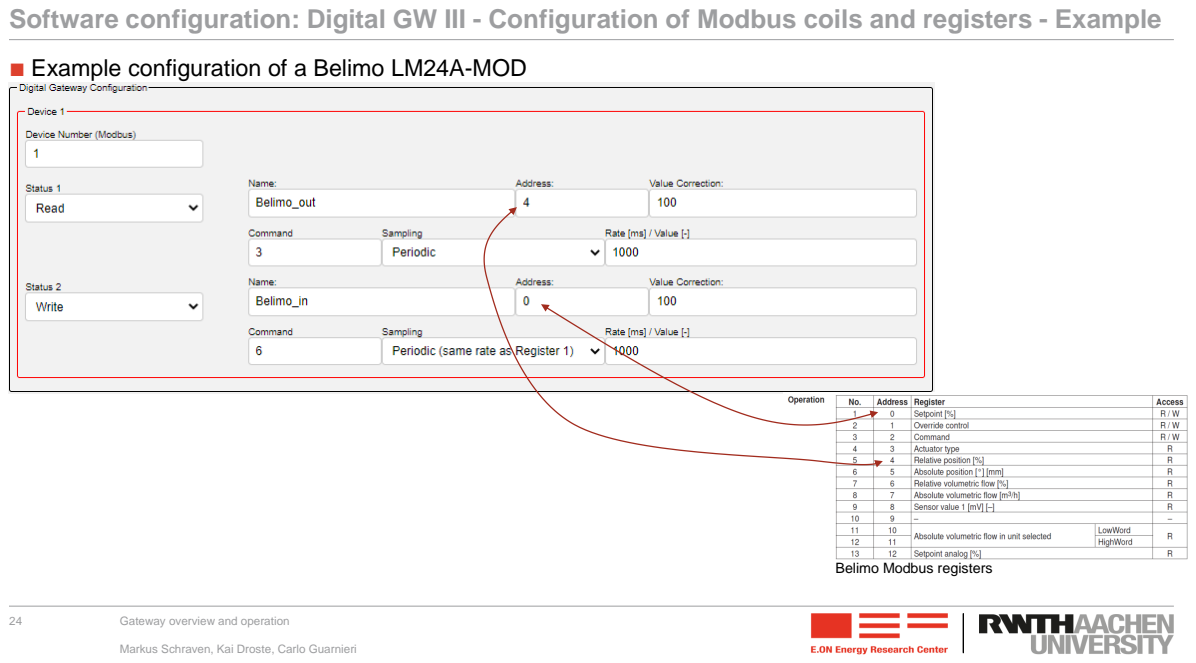
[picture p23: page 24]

■ Example configuration of a Belimo LM24A-MOD

Belimo Modbus registers

### Functionalities implemented to the CFG button

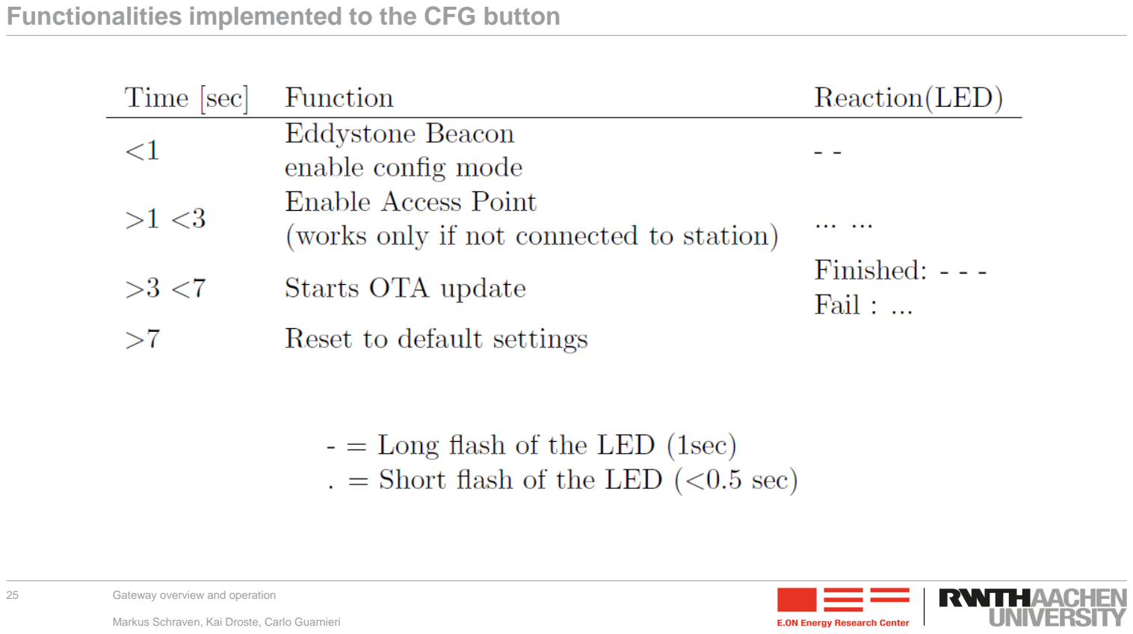
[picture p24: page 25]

# Operators instructions II - Inital setup / Flashing the firmware

### Operators instructions II - Initial setup / Flashing the firmware - Menuconfig

■ For the firmware to be flashed, it has to be compiled first
on your computer
■ Start a terminal (CMD/PowerShell)
■ cd into the repository of the Gateway software
■ Start the ESP-IDF

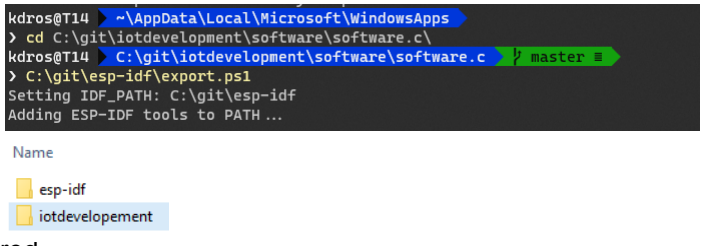
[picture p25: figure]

≡ This obviously requires the ESP-IDF to be installed and configured
≡ For further information on installing and configuring the ESP-IDF, see https://docs.espressif.com/projects/esp-idf/en/latest/esp32/get-started/index.htmlhttps://docs.espressif.com/projects/esp-idf/en/latest/esp32s2/get-started/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 ≡ Alternatively, one can use the preconfigured terminal from the ESP-IDF and navigate into the repository from there

Disclaimer: All commands shown here are executed in Windows Powershell or Windows Terminal

### Operators instructions II - Initial setup / Flashing the firmware - Menuconfig

■ For practicality, the repository already contains 3 different configurations (analog, temperature, digital)

≡ sdkconfig.aio
≡ sdkconfig.tmp
≡ sdkconfig.dio
■ To choose a configuration, copy and rename one of them to sdkconfig ■ Subsequently, the configuration should be validated in the menuconfig

■ Leave the menuconfig hitting the ESC key

In this example, the analog configuration has been copied → the menuconfig shows „analog“ as selected interface → configuration is correct The menu can be closed hitting the ESC key

Disclaimer: All commands shown here are executed in Windows Powershell or Windows Terminal

Operators instructions II - Initial setup / Flashing the firmware - Build / Connecting the

### programmer

■ The firmware can now be compiled with the selected configuration

≡ idf.py build

■ Programmer

≡ 6-pole cable → used for flashing the firmware
≡ 8-pole cable → JTAG (can be used for an inline debugging of the ESP)
≡ The 6-pole cable has to be connected in a way, that it matches the Pin assignement on the Gateway! = E. g., compare the PCB solder point: The squared solder point marks PIN 1 on each device

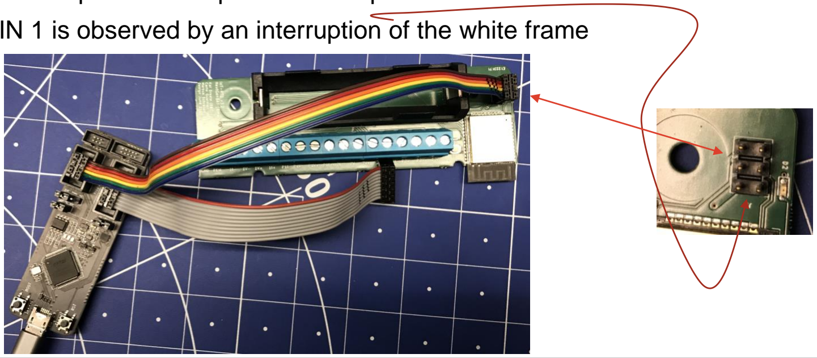
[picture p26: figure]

= From top perspective, PIN 1 is observed by an interruption of the white frame

PIN 1

Disclaimer: All commands shown here are executed in Windows Powershell or Windows Terminal

### Operators instructions II - Initial setup / Flashing the firmware - Flash, Monitor

■ Flashing the firmware to the Gateway

≡ idf.py flash

■ Serial monitor (for debugging and checking the version/firmware)

≡ idf.py monitor
≡ Basically a command line printing info, debug and error messages

≡ The debug level can be adjusted in the menuconfig (idf.py menuconfig)
≡ Might be necessary to specify the port by adding –p com6 (e. g. for serial port COM6)

■ Commands can be combined / executed one after the other in one command (flash also incorporates the build command)

≡ E. g., idf.py flash monitor
≡ Or idf.py menuconfig flash monitor

Disclaimer: All commands shown here are executed in Windows Powershell or Windows Terminal

# Developers instructions - Development / Adjusting the firmware

### Developers instructions - Development / Adjusting the firmware

■ The header files (*.h) are, for the most part, commented within the code

≡ From these, a Doxygen documentation has been created
= It is accessed via the index.html in OSIGBApp/Firmware/doc/doxygen/html at main · RWTH-EBC/OSIGBApp (github.com) (https://github.com/RWTH-EBC/OSIGBApp/tree/main/Firmware/doc/doxygen/html)
≡ In VSCode, you can access the related header file to a function by marking the function and pressing F12
= This may help to better understand the origin and operating principle of the selected function

■ For adding new variables that are coupled to the configuration (web interface), please consider the steps documented at OSIGBApp/aio_configurator.md at main · RWTH-EBC/OSIGBApp (github.com)The process is quite tedious (currently requires multiple (https://github.com/RWTH-EBC/OSIGBApp/blob/main/Firmware/doc/markdown/aio_configurator.md) conversions and a specific order) and will be revised in future development

### VSCode

■ If you are in a terminal (powershell), VSCode can be started

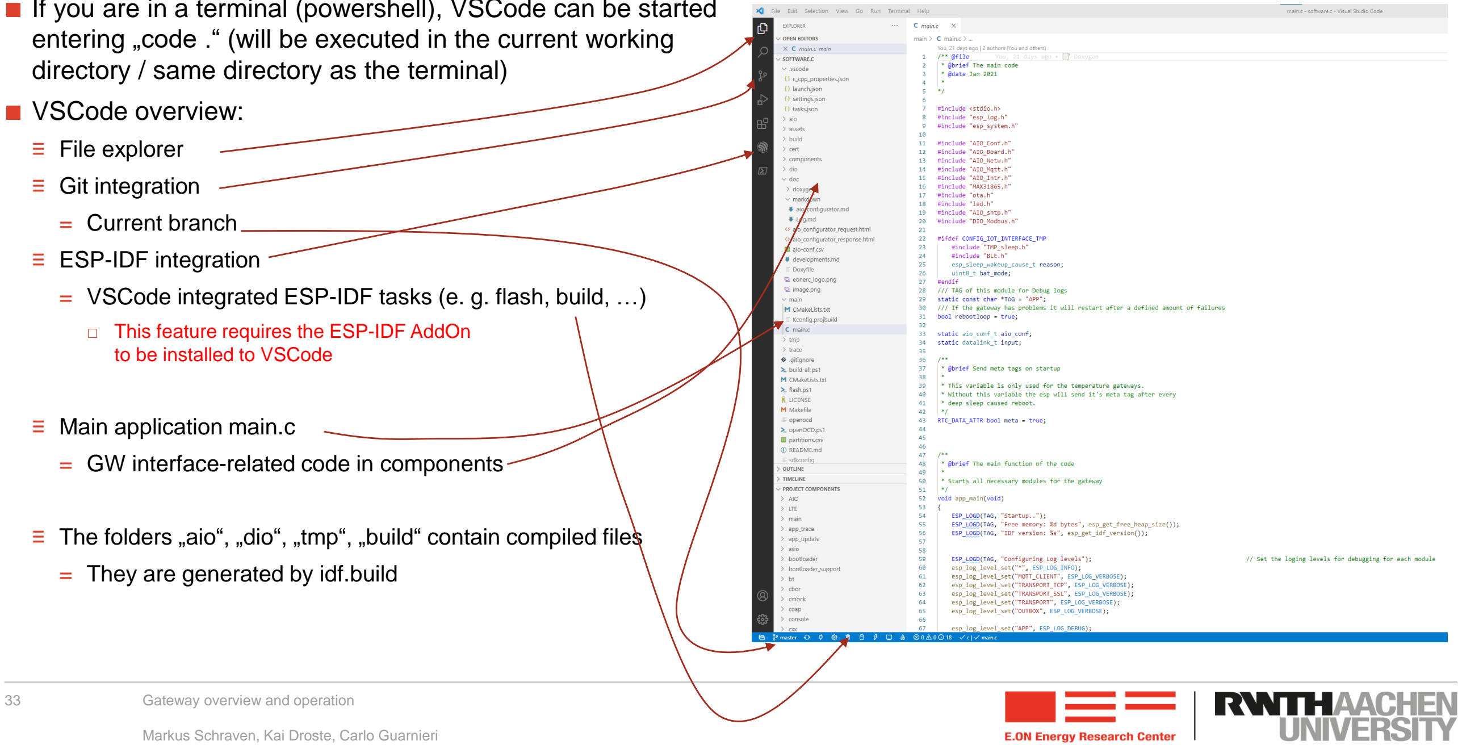
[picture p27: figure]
■ VSCode overview:; ≡ File explorer; ≡ Git integration; = Current branch; ≡ ESP-IDF integration; to be installed to VSCode; ≡ Main application main.c; = They are generated by idf.build

entering „code .“ (will be executed in the current working directory / same directory as the terminal)

= VSCode integrated ESP-IDF tasks (e. g. flash, build, …)

□ This feature requires the ESP-IDF AddOn

= GW interface-related code in components

≡ The folders „aio“, „dio“, „tmp“, „build“ contain compiled files

### Measurement Accuracy I

■ Max31865 RTD to digital converter

≡ 15 Bit ADC resolution
= 0.03125 °C
≡ → 0.5 °C
≡ 21ms (max) conversion Time
■ EL3214 | 4-channel input terminal PT100 (RTD)

≡ 0.1 °C resolution
≡ 170 ms sampling rate

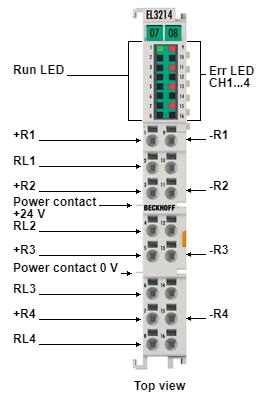
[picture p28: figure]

https://www.beckhoff.de/default.asp?ethercat/el3214.htm

https://datasheets.maximintegrated.com/en/ds/MAX31865.pdf

### Measurement Accuracy II

■ MCP3021 analog to digital converter

≡ 10 Bit resolution

■ EL3068 | 8-channel analog input terminal 0…10 V

≡ 12 Bit resolution

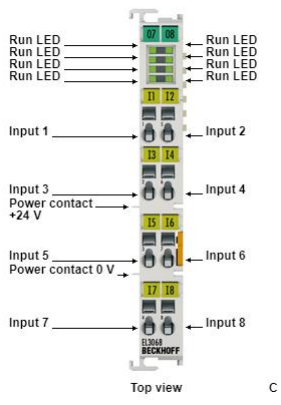
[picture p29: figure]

https://eu.mouser.com/datasheet/2/268/21805a-74229.pdf | https://www.beckhoff.de/default.asp?ethercat/el3068.htm

### Power consumption

■ Digital GW

≡ Standby 20 mA, 24 V, 0,48 W

■ Temp GW

≡ Standby 10-20 mA, 24 V, 0,24-0,48 W

■ Analog GW

≡ Standby 20 mA, 24 V, 0,48 W | https://www.trox.de/zonenmodule/x-air-zmo-f9b1738e5431ff98

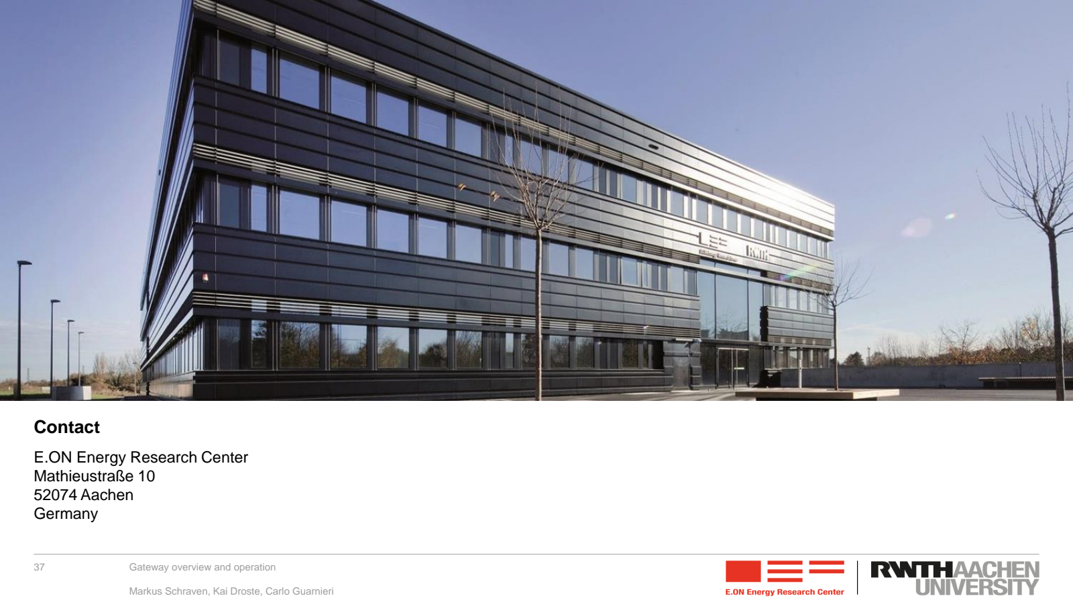
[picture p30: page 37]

E.ON Energy Research Center Mathieustraße 10
52074 Aachen
Germany

Contact

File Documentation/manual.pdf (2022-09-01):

# IoT Gateways

# 1 IoT Gateways

This Manual describes how to set up the IoT Gateways. There are three different Gateways available:

- Analog (0(2)–10 V, 0(4)–20 mA)

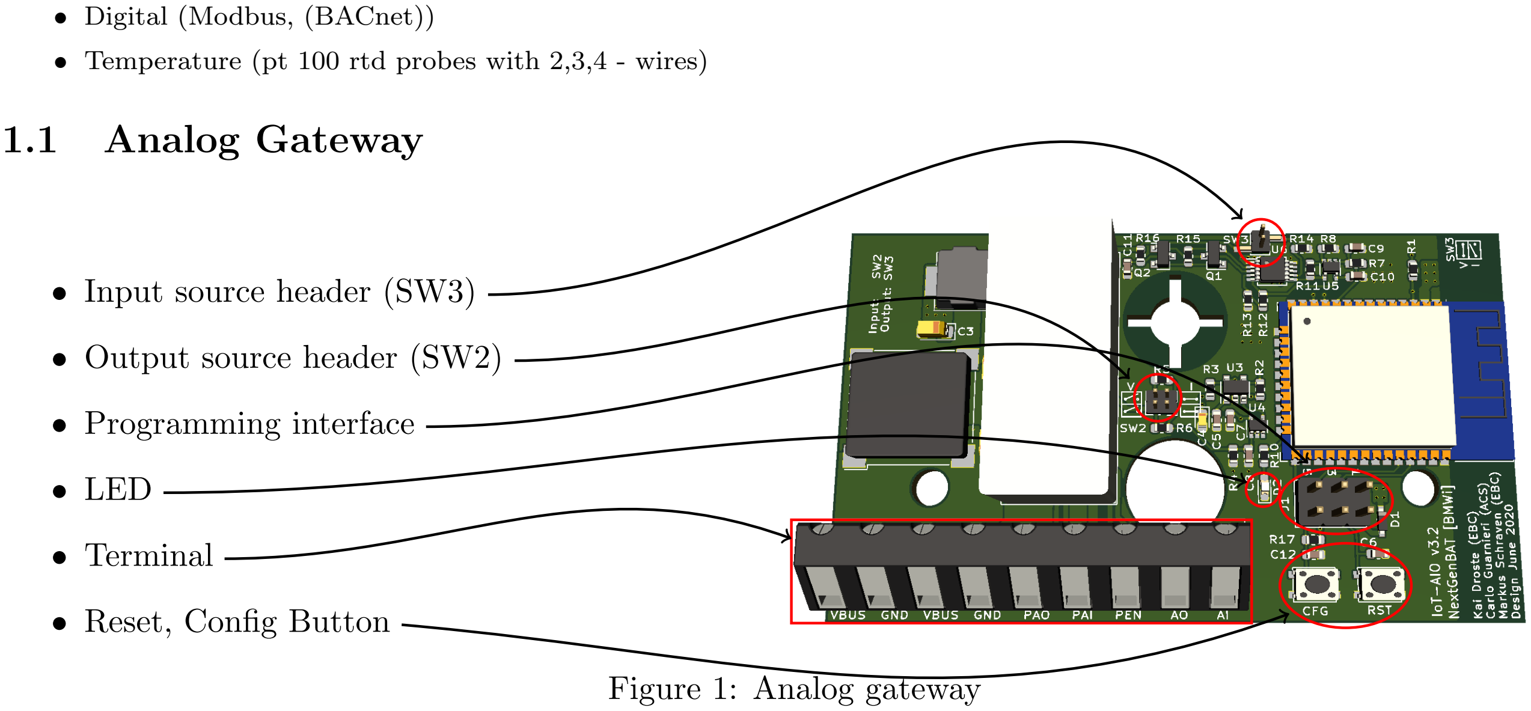
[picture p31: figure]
• Digital (Modbus, (BACnet)); 1.1 Analog Gateway; • Input source header (SW3); • Output source header (SW2); • Programming interface; • LED; • Terminal; • Reset, Config Button; Figure 1: Analog gateway

- Temperature (pt 100 rtd probes with 2,3,4 - wires)

### Table 1: Analog terminal

VBUS | + 24 V | Input
GND | GND | Input
VBUS | + 24 | Output to field device
GND | GND | Output to field device
PAO | AO to plc | Not in use
PAI | AI to plc | Not in use
PEN | + 24 V | Enable Gateway (necessary)
AO | 0 -10 V / 0 - 10 mA | Analog output (single-ended)
AI | 0 -10 V / 0 - 10 mA | Analog input (single-ended)

To set the input to voltage mode, both headers at SW2 need to be disconnected. To set the input to current mode, both headers need to be connected with header jumpers according to the pictogram (I) .
To set the output to voltage mode, the header at SW3 need to be connected with header jumpers according the pictogram (V). To set the output to current mode, the header need to be disconnected.

## 1.2 Temperature Gateway

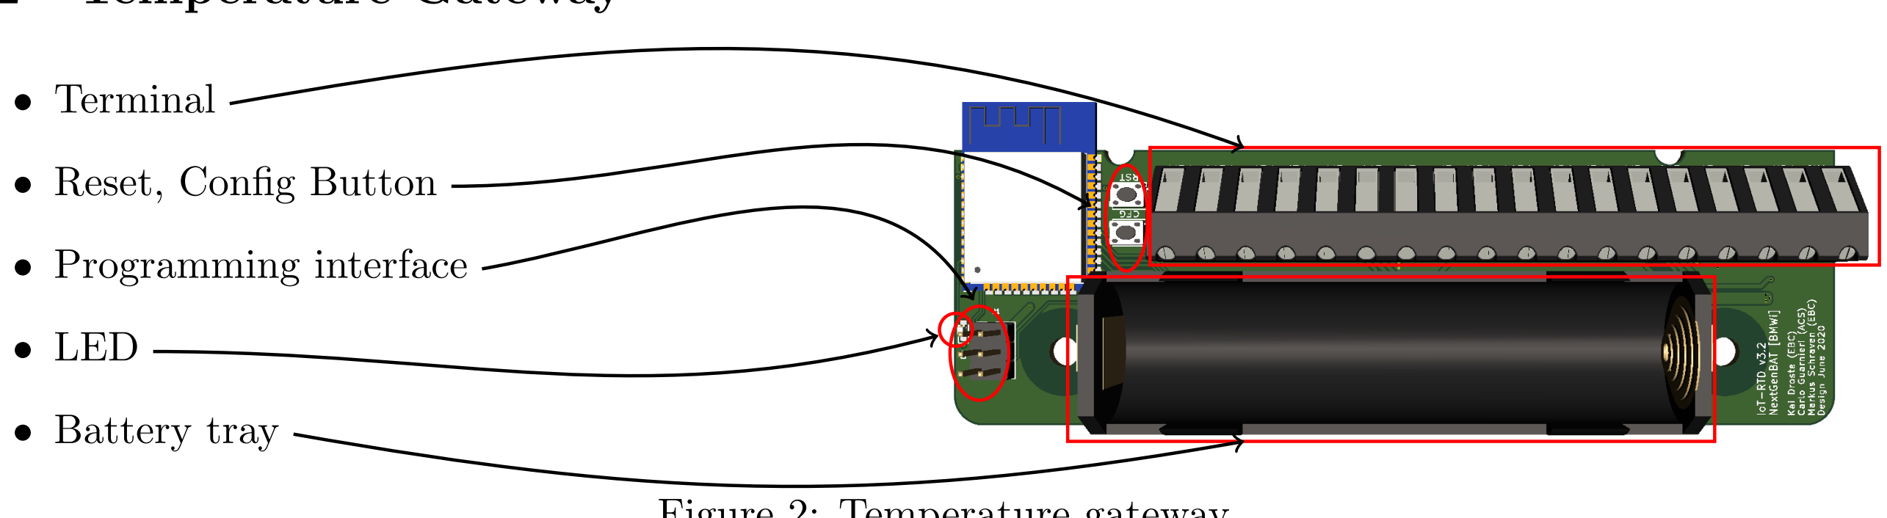
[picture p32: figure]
• Terminal; • Reset, Config Button; • Programming interface; • LED; • Battery tray

### Figure 2: Temperature gateway

### Table 2: Temperature terminal

GND | Do not connect | Not in use
PEN | Do not connect | Not in use
1I- | | RTD probe 1
1V- | | RTD probe 1
1V+ | | RTD probe 1
1I+ | | RTD probe 1
P1I- | to plc | RTD probe 1 not in use
P1V- | to plc | RTD probe 1 not in use
P1V+ | to plc | RTD probe 1 not in use
P1I+ | to plc | RTD probe 1 not in use
2I- | | RTD probe 2
2V- | | RTD probe 2
2V+ | | RTD probe 2
2I+ | | RTD probe 2
P2I- | to plc | RTD probe 2 not in use
P2V- | to plc | RTD probe 2 not in use
P2V+ | to plc | RTD probe 2 not in use
P2I+ | to plc | RTD probe 2 not in use

### Set up the gateway for 2,3,4 - Wire RTD-probes

In the Configurator pt100 or pt1000 can be chosen. Since the gateways are all setup for pt100 probe, to use pt1000 probes the reference resistor has to be changed on the board (Reference resistor = R13 (or R5), see Figure 3).

To set the gateways for 2, 3 or 4 wires, it is required to solder bridges on the board according to the following image:

### For example: For a three wire probe the solder

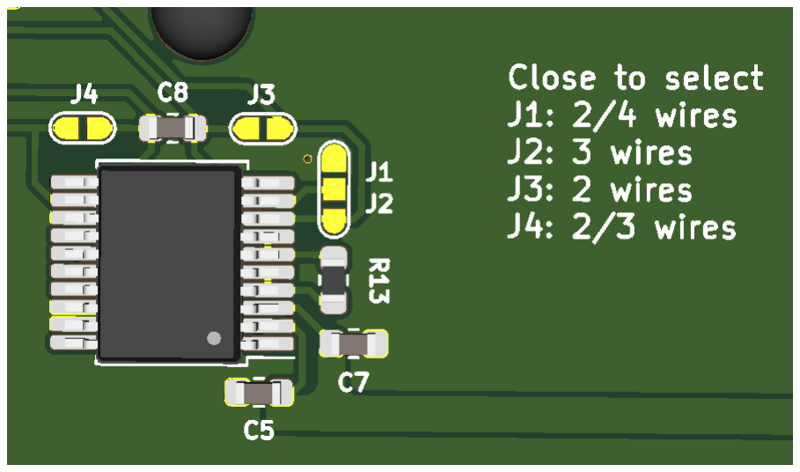
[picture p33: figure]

joints J2 and J4 need to be closed.

### - For a two wire probe, connect V+ and V-

with the rtd-probe.

### - For a three wire probe, connect I+, V+ and

V- with the rtd-probe.

### - For a four wire probe, connect I+, V+, I-

and V- with the rtd-probe.

### Figure 3: Setting the temperature gateway for different types

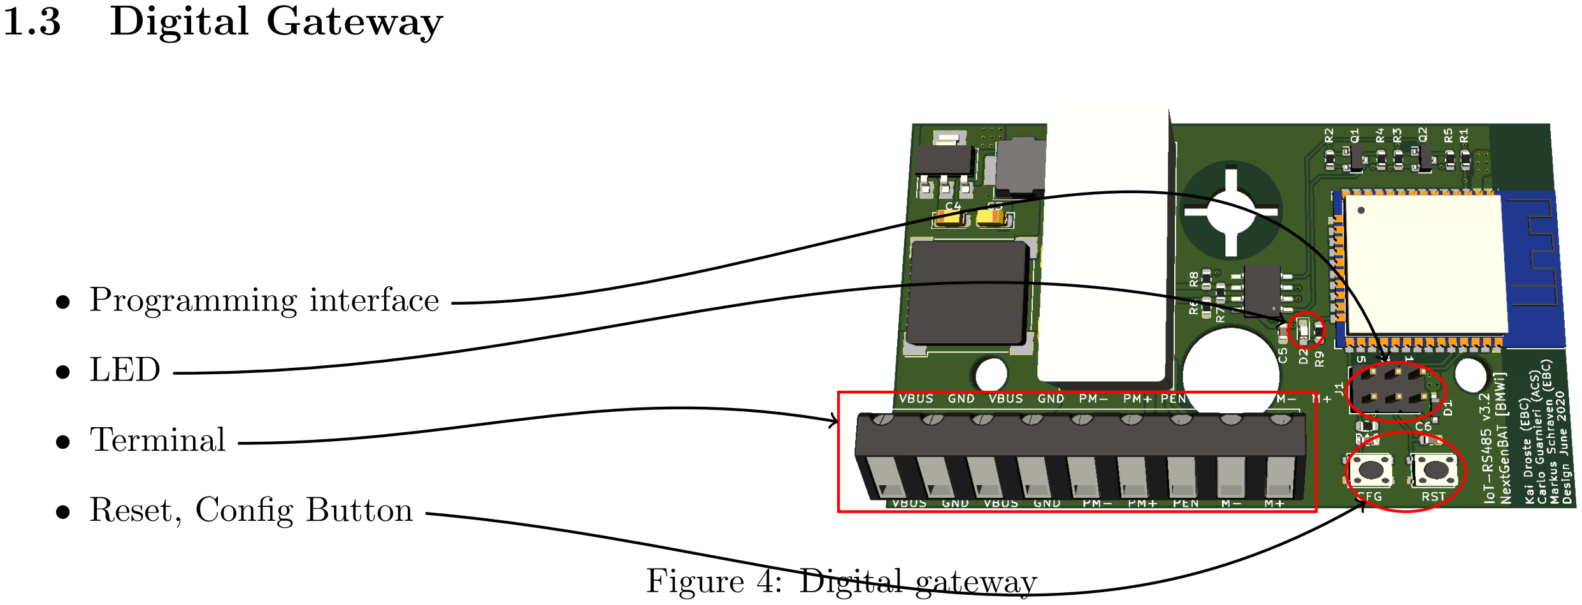
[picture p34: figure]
1.3 Digital Gateway; • Programming interface; • LED; • Terminal; • Reset, Config Button; Figure 4: Digital gateway

### Table 3: Digital terminal

VBUS | + 24 V | Input
GND | GND | Input
VBUS | + 24 | Output to field device
GND | GND | Output to field device
PM- | M- to plc | Not in use
PM+ | M+ to plc | Not in use
PEN | + 24 V | Enable Gateway (necessary)
M- | RS485 - Line
M+ | RS485 + Line

# 2 Buttons

The Gateways are equipped with two Buttons. The Reset (RST) button restarts the device. The Config (CFG) Button has different functions according to the duration it is pressed.

### Table 4: CFG Button modes

Time [sec] | Function | Reaction(LED)

t < 1

### Eddystone Beacon

enable config mode | - -

1 < t < 3

### Enable Access Point

(works only if not connected to station) | ... ...
3 < t < 7 | Starts OTA update | Finished: - - -
Fail : ...
t > 7 | Reset to default settings

### - = Long flash of the LED (1sec) . = Short flash of the LED (<0.5 sec)

Since the Gateways support deep sleep mode, it could be necessary to initiate the configuration process with a short press on the RST button. After pressing the RST button, the device needs up to 4 seconds to fully boot up.

# 3 Iot Configurator

The IoT Configurator is the Webinterface from the IoT-Gateway-Software. It is accessed by redirecting to the IP of the gateway. To find out the right IP of the gateway, the Eddystone-BLE-Beacon (see section 2) can be used.

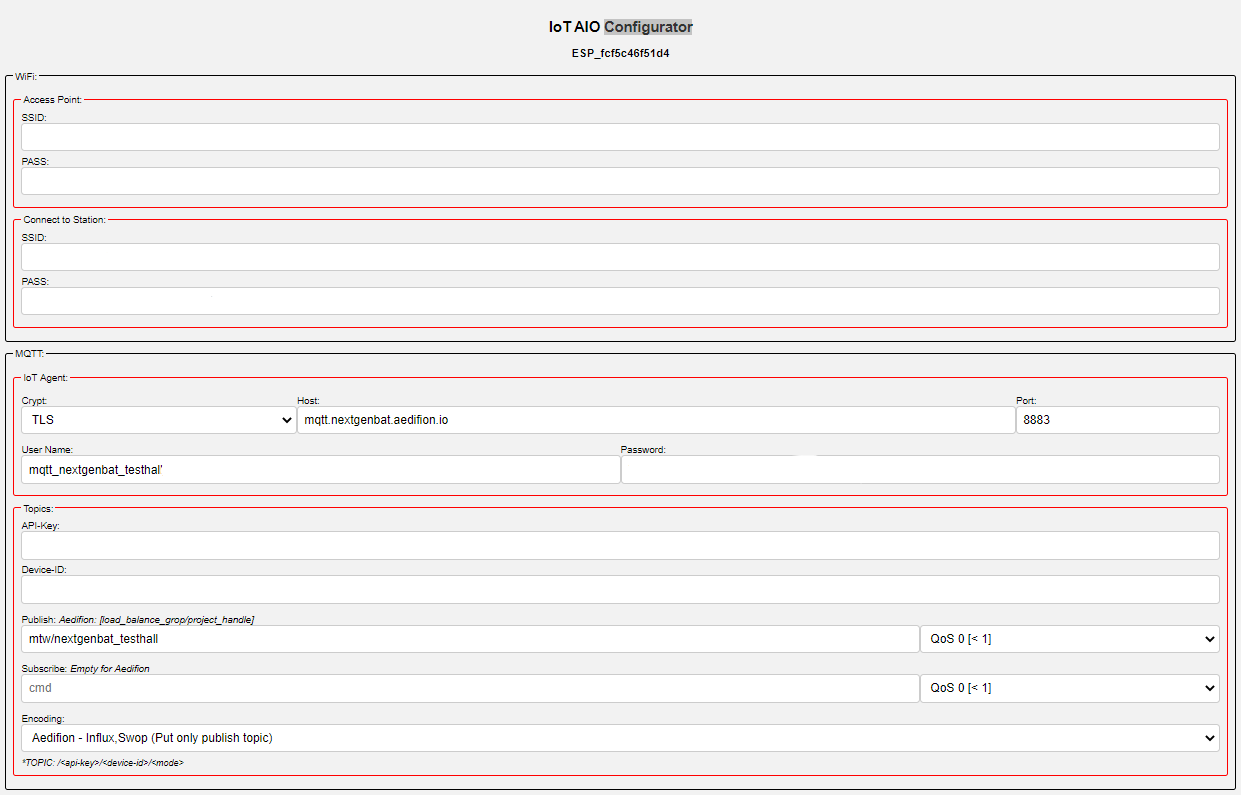
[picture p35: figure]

### Figure 5: IoT Configurator

## 3.1 Wifi

The gateway operates as WiFi Access Point or allows connecting to an existing one. Both of this can run in parallel.

### Access Point

The Access Point mode should only be used for configuration. For example, to save the station credentials on the device. The SSID defaults to a device specific name which is composed from ESP and the device’s MAC-Address(for example: ESP fcf5c46f51d4). Hence, every gateway has it’s own unique name to distinguish the devices from each other. The password is by default: 123456789

### Station

If credentials are entered here, the gateway will try to connect to this Access Point.

## 3.2 MQTT

The Device will communicate with a cloud server using the MQTT protocol (https://github.com/mqtt/mqtt.github.io/wiki). This manual will focus on the connection to the Aedifion (https://www.aedifion.com/) Cloud-platform. However, the gateways also support different MQTT brokers.

### Topics

For connection with Aedifion, the API-Key and Device-ID boxes are not used. Changes to the QoS(Quality of Service) will have no affect on the device’s behavior either.
The Publish topic requires only the main Aedifion topic name: For example: ‘mtw/nextgenbat testhall‘. The following topics will be automatically generated by the device:
- META/mtw/nextgenbat testhall
- CONTROLS/mtw/nextgenbat testhall
- mtw/nextgenbat testhall/update

The Aedifion encoding will send the values through the InfluxDB protocol (see Figure 6). (https://docs.influxdata.com/influxdb/v1.8/write protocols/line protocol tutorial/)

1 | Datapointname value =20.0 1465839830100400200

### Figure 6: Influx message: datapoint, observation, timestamp

The device will receive SWOP(https://aedifion.gitlab.io/swop/) messages on the CONTROLS/... Topic (see Figure 7).

1 | {
2 | " type ": | " NEWSPT ",
3 | " swop - version ": 0.1,
4 | " datapoint ": | " bacnet 93-4120- External - Room - Set - Temperature - RTs ",
5 | " value ": | 20.3,
6 | " priority ": | 13
7 | }

### Figure 7: SWOP message

If the name of a data point matches the name of the SWOP message, the gateway will set the connected device to the given value. On each Startup of the gateway, the Metadata will be send to the META/... topic. (see Figure 8)

1 | {
2 | " name ": | " Name of device ",
3 | " IP ": | "192.168. xxx . xxx ",
4 | " source ": | " Analog Gateway "
5 | }

### Figure 8: META tag

## 3.3 Data point names

For data point naming, we use BUDO (https://github.com/RWTH-EBC/BUDO). BUDO is intended to provide META data in a hierarchical structure allowing artificial-intelligence-based algorithms to identify interrelated devices and topologies. The Gateway will automatically parse the unit and send it together with the META-Tags to the Aedifion server. Other names or device keys are applicable as well.

## 3.4 Periodic or Threshold

The gateway can publish recorded values periodically or using change of value (COV) (compare Figure 9). If COV is used the device will check every second the values. If the deviation of one value exceeds the threshold, all values of the gateway will be published to the MQTT server. In periodic mode the unit is millisecond. In threshold mode, the values are absolute values.

# 4 Analog Gateway configuration

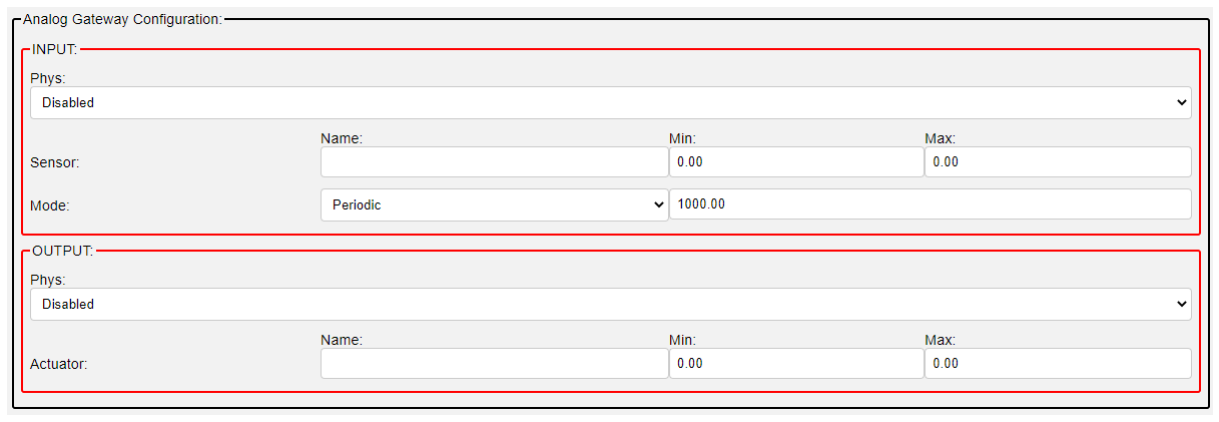
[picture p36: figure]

### Figure 9: Analog configurator

For the analog gateway, data point names and a user-defined scaling are configured in the Analog Gateway Configuration section. The analog gateway supports the following interfaces:
- 0(2) - 10 V
- 0(4) - 20 mA

The gateway will scale the input and output according to the user-defined values for minimum and maximum. For example, a 2-10 V signal with a 0-100 % scaling will map 0 % to 2 V and 100 % to 10 V and values within this range accordingly.

# 5 Temperature Gateway configuration

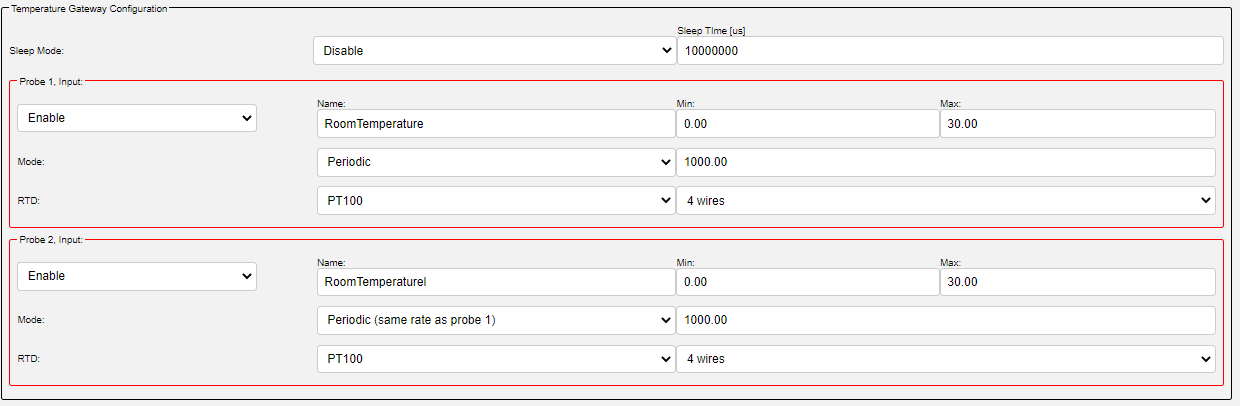
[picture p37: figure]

### Figure 10: Temperature configurator

For the temperature gateway, data point names, the operational limits and the type of the rtd probe are configured in the Temperature Gateway configuration section.

If the measured value is not within the min and max values, no new value is sent to the cloud server. This is used to protect the device from sending values outside of the operational limits.

To achieve the longest possible battery life, it is necessary to set Sleep Mode to enable and use the threshold mode.

# 6 Digital Gateway configuration

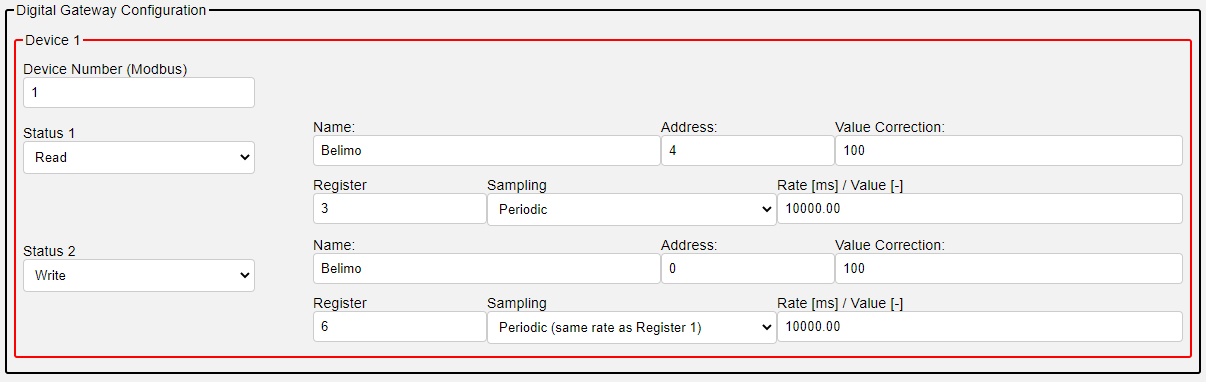
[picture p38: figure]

### Figure 11: Digital configurator

For the digital gateway, data point names, a user-defined scaling and the connected Modbus device are configured in the Digital Gateway Configuration section.

This configuration is limited to one device and two registers. This limit is only given by the configuration interface. The implemented Modbus stack will support multiple devices and registers.

The Device Number is the Modbus device number. This can be found in the manual of the connected device or can be set manually. The name box declares the data point name. This is used for the communication with the Aedifion server.

Each Modbus register can be set up with a read or write command. The function code relates to the register type (input, holding, coil, discrete input; for reference see the Modbus documentation) and should be defined in the Register box. The correct values can be found in the manual of the field device. In the address field, the corresponding register address has to be entered which is usually given by the vendor in the data sheet of the field device.

To adjust the output value, the correction box needs to be filled. The real value from the field device is then divided by the given value in the input box.
For example:
The Belimo Modbus devices store their set points in a value between 0 and 10000. If a 0 to 100 % representation is desired, the incomming signal has to be divided by factor 100.

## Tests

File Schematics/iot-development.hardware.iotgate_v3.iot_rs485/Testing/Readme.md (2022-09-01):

# Test Routine (outdated --> software.c)

## Function of the Board
 - [ ] On Board LED
 - [ ] WLAN
 - [ ] Switching between Input to ESP and Input to other output
 - [ ] UART to RS485 converter

### Testing On Baord LED and WLAN
 #### Todo: 
 [ ] Add Blinking LED to Code

 Use the code which Carlos AIO_sw code to test it. After flashing the Code will run the ESP into Access Point \[AP] Mode. If the AP is  established the on Board LED will light up. Now you can connect to the board and set the right wifi credentials. If Wifi mode swichted to Station Mode the LED will swicht off. 

### Testing the switching Relay

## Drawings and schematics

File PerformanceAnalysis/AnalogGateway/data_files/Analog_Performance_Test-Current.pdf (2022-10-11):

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

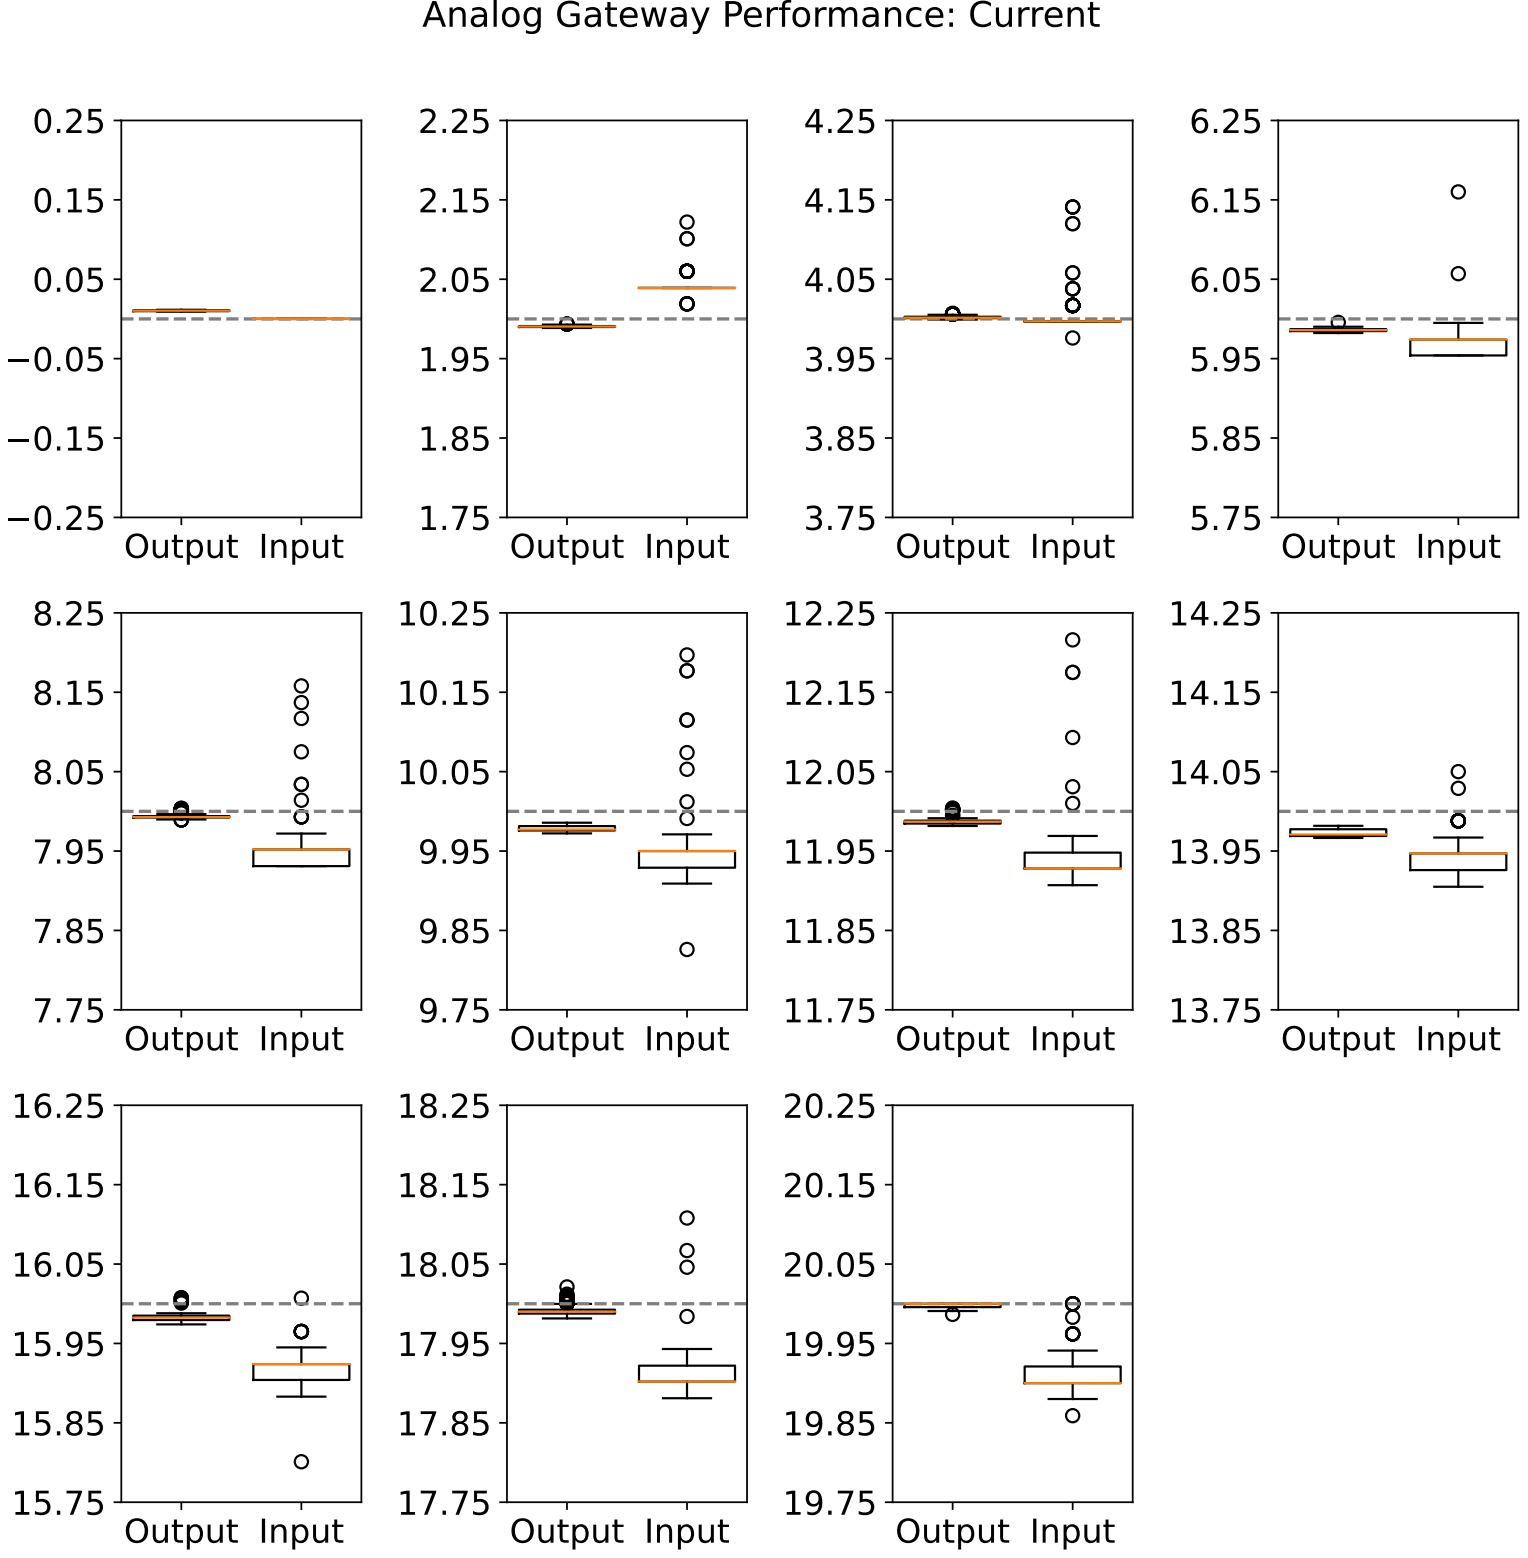
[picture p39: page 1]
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

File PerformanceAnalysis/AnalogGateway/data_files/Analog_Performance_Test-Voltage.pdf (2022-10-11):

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

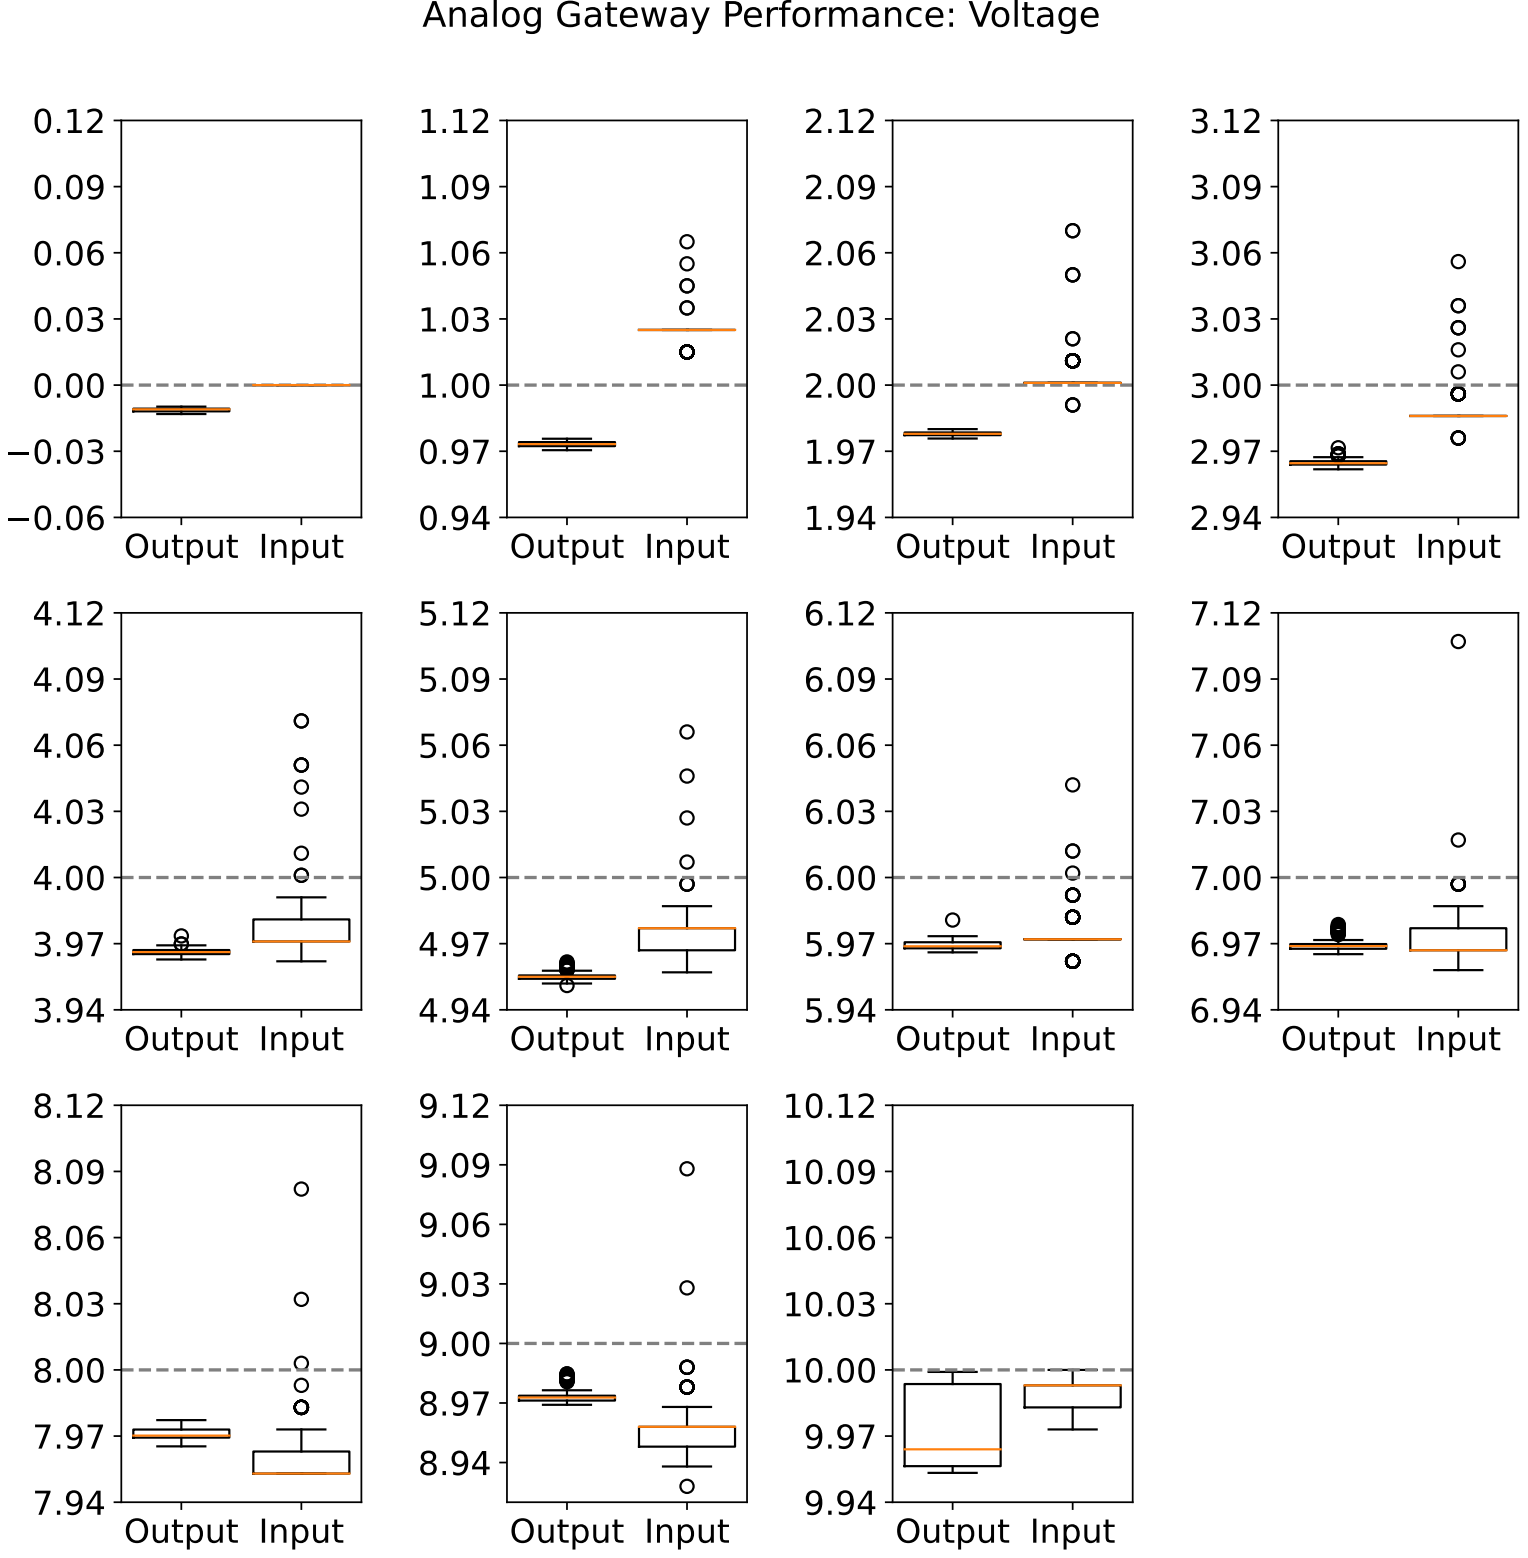
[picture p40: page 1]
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

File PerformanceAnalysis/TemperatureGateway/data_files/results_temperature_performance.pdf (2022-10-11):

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

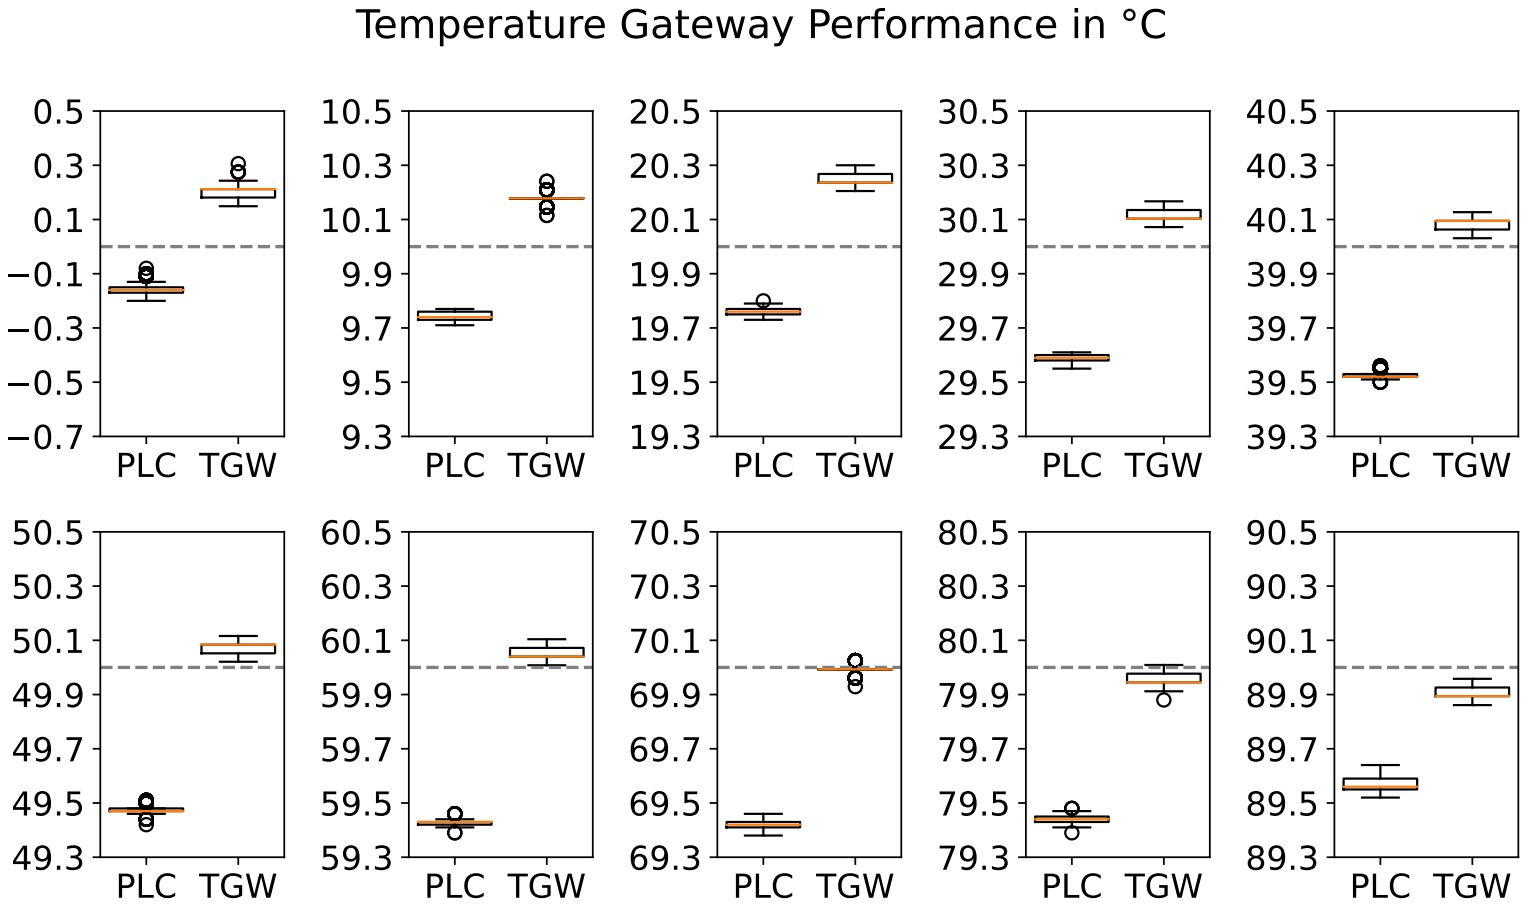
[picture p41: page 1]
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

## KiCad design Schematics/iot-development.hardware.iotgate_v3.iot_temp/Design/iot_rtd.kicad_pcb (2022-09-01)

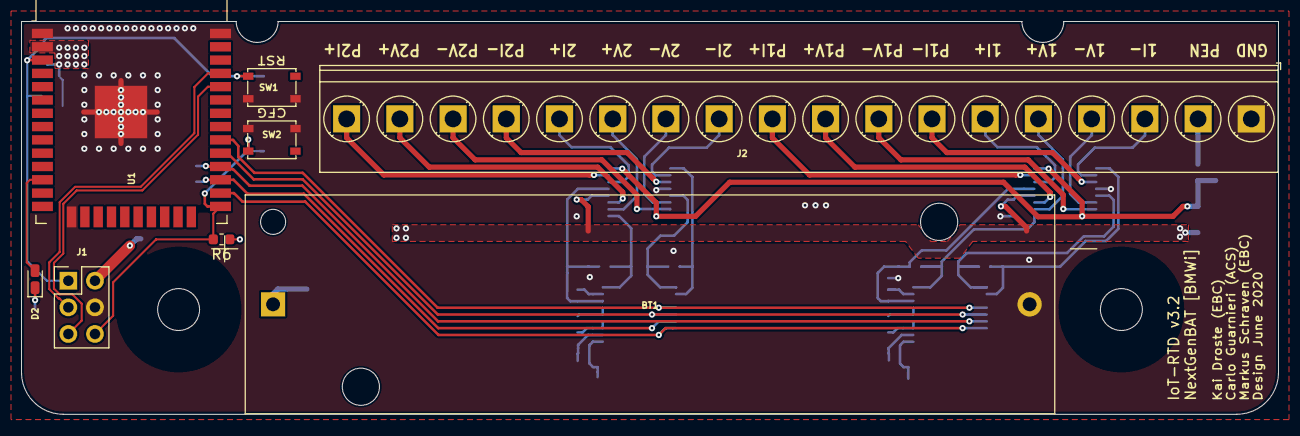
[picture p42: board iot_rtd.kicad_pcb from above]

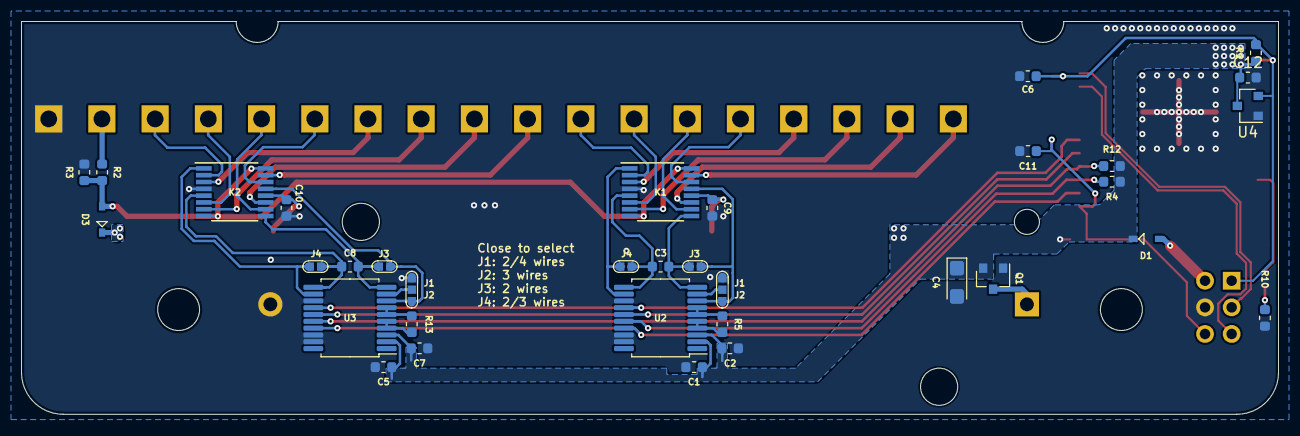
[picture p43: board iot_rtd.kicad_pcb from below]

Board: 2 copper layers, 120.0 x 37.5 mm, 42 parts (34 on the bottom side), 47 nets.

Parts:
BT1: LiFePo4 18650; BatteryHolder_Keystone_1043_1x18650
C1, C2, C5, C6, C7, C9, C10, C11, C12: 100n; C_0603_1608Metric
C3, C8: 1u; C_0603_1608Metric
C4: 10u; CP_EIA-3216-18_Kemet-A
D1, D3: BAT60A
D2: 150060RS75000; LED_0603_1608Metric_Castellated
J1: Conn_02x03; PinHeader_2x03_P2.54mm_Vertical
J2: TB004-508-18
JP1, JP4: Wires; SolderJumper-3_P1.1mm_Open_RoundedPad0.8x0.9mm
JP2, JP3, JP5, JP6: Wires; SolderJumper-2_P1.1mm_Open_RoundedPad0.8x0.9mm
K1, K2: TS3A44159; TSSOP-16_4.4x5mm_P0.65mm
Q1: Si2323; SOT-23
R1, R6: 10k; R_0603_1608Metric
R2: 6.8k; R_0603_1608Metric
R3: 1k; R_0603_1608Metric
R4, R12: 3.3k; R_0603_1608Metric
R5, R13: 402 0.1%; R_0603_1608Metric
R10: 270; R_0603_1608Metric
SW1, SW2: PTS815
U1: ESP32-WROOM-32D
U2, U3: MAX31865; SSOP-20_5.3x7.2mm_P0.65mm
U4: TLV803S; SOT-23

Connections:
+3V3: C1.2, C2.2, C4.1, C5.2, C7.2, C9.2, C10.2, C12.1, D1.1, D3.1, K1.12, K2.12, Q1.2, R1.1, R4.1, R6.1, R12.1, U1.2, U2.2, U2.3, U3.2, U3.3, U4.3
/1_I+: J2.6, K2.14
/1_I-: J2.3, K2.2
/1_V+: J2.5, K2.10
/1_V-: J2.4, K2.6
/2_I+: J2.14, K1.14
/2_I-: J2.11, K1.2
/2_V+: J2.13, K1.10
/2_V-: J2.12, K1.6
/ESP_1I+: JP4.3, JP5.1, K2.13, U3.8
/ESP_1I-: JP6.2, K2.1, U3.12
/ESP_1V+: C8.1, JP5.2, K2.9, U3.10
/ESP_1V-: C8.2, JP6.1, K2.5, U3.11
/ESP_2I+: JP1.3, JP2.1, K1.13, U2.8
/ESP_2I-: JP3.2, K1.1, U2.12
/ESP_2V+: C3.1, JP2.2, K1.9, U2.10
/ESP_2V-: C3.2, JP3.1, K1.5, U2.11
/ESP_CS1: R12.2, U1.28, U3.16
/ESP_CS2: R4.2, U1.27, U2.16
/ESP_DBG: D2.2, U1.12
/ESP_EN: C6.1, J1.1, R1.2, SW1.1, U1.3, U4.2
/ESP_IO0: C11.1, J1.6, R6.2, SW2.1, U1.25
/ESP_RXD: J1.5, U1.34
/ESP_SCK: U1.29, U2.15, U3.15
/ESP_SDI: U1.30, U2.14, U3.14
/ESP_SDO: U1.26, U2.17, U3.17
/ESP_TXD: J1.3, U1.35
/PLC_1I+: J2.10, K2.15
/PLC_1I-: J2.7, K2.3
/PLC_1V+: J2.9, K2.11
/PLC_1V-: J2.8, K2.7
/PLC_2I+: J2.18, K1.15
/PLC_2I-: J2.15, K1.3
/PLC_2V+: J2.17, K1.11
/PLC_2V-: J2.16, K1.7
/PLC_EN: J2.2, R2.1
/PLC_ENX: D3.2, K1.8, K1.16, K2.8, K2.16, R2.2, R3.1
GND: BT1.2, C1.1, C2.1, C4.2, C5.1, C6.2, C7.1, C9.1, C10.1, C11.2, C12.2, J1.4, J2.1, JP1.1, JP4.1, K1.4, K2.4, Q1.1, R3.2, R10.2, SW1.2, SW2.2, U1.1, U1.15, U1.38, U1.39, U2.13, U2.18, U2.19, U3.13, U3.18, U3.19, U4.1
unnamed: BT1.1, Q1.3
unnamed: D2.1, R10.1
unnamed: JP1.2, U2.9
unnamed: JP4.2, U3.9
unnamed: R5.1, U2.4, U2.5
unnamed: R5.2, U2.6, U2.7
unnamed: R13.1, U3.4, U3.5
unnamed: R13.2, U3.6, U3.7
VCOM: D1.2, J1.2

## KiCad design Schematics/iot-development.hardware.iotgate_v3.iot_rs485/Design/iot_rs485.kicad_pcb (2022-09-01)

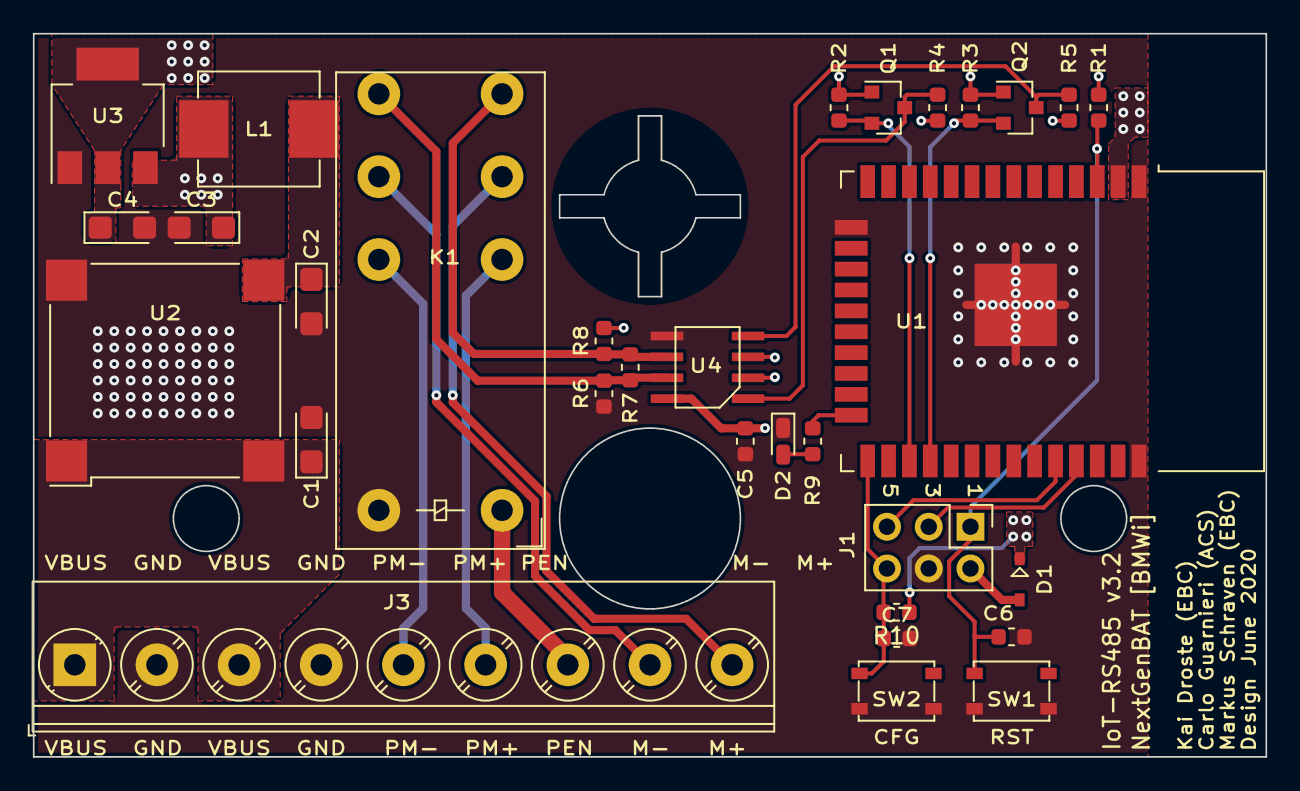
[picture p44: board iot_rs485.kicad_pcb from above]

Board: 2 copper layers, 75.0 x 44.0 mm, 31 parts (0 on the bottom side), 23 nets.

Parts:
C1, C4: 10u; CP_EIA-3216-18_Kemet-A
C2, C3: 22u; CP_EIA-3216-18_Kemet-A
C5, C6, C7: 100n; C_0603_1608Metric
D1: BAT60A
D2: 150060RS75000; LED_0603_1608Metric_Castellated
J1: Conn_02x03; PinHeader_2x03_P2.54mm_Vertical
J3: Conn_01x09; TerminalBlock_CUI
K1: RT424024; Relay_DPDT_RT424024
L1: 22u; HM72L-0630
Q1, Q2: 2N7002; SOT-23
R1, R2, R3, R4, R5, R10: 10k; R_0603_1608Metric
R6, R8: 220; R_0603_1608Metric
R7: 120; R_0603_1608Metric
R9: 270; R_0603_1608Metric
SW1, SW2: PTS815
U1: ESP32-WROOM-32D
U2: VXO7805-500-M; VXO78-500-M
U3: AZ1117IH-3.3; SOT-223-3_TabPin2
U4: MAX13487

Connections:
+3V3: C4.1, D1.1, Q1.1, Q2.1, R1.1, R2.1, R3.1, R10.1, U1.2, U3.2
+5V: C3.1, C5.1, L1.2, R4.2, R5.1, R8.1, U3.3, U4.2, U4.3, U4.8
/ESP_DBG: R9.1, U1.24
/ESP_EN: C6.1, J1.1, R1.2, SW1.1, U1.3
/ESP_IO0: C7.1, J1.6, R10.2, SW2.1, U1.25
/ESP_M+: K1.24, R7.1, R8.2, U4.6
/ESP_M-: K1.14, R6.1, R7.2, U4.7
/ESP_RXD: J1.5, U1.34
/ESP_RXD2: Q1.2, R2.2, U1.27
/ESP_TXD: J1.3, U1.35
/ESP_TXD2: Q2.2, R3.2, U1.28
/M+: J3.9, K1.21
/M-: J3.8, K1.11
/PLC_M+: J3.6, K1.22
/PLC_M-: J3.5, K1.12
/~PLC_EN: J3.7, K1.A2
GND: C1.2, C2.2, C3.2, C4.2, C5.2, C6.2, C7.2, D2.1, J1.4, J3.2, J3.4, K1.A1, R6.2, SW1.2, SW2.2, U1.1, U1.15, U1.38, U1.39, U2.2, U3.1, U4.5
unnamed: C2.1, L1.1, U2.3
unnamed: D2.2, R9.2
unnamed: Q1.3, R4.1, U4.1
unnamed: Q2.3, R5.2, U4.4
VBUS: C1.1, J3.1, J3.3, U2.1, U2.4
VCOM: D1.2, J1.2

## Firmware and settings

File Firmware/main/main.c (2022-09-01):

/** @file 
 * @brief The main code
 * @date Jan 2021
 * 
*/

#include <stdio.h>
#include "esp_log.h" 				
#include "esp_system.h"

#include "Conf.h"
#include "AIO_Board.h"
#include "Netw.h"
#include "Mqtt.h"
#include "Intr.h"
#include "TMP_MAX31865.h"
#include "ota.h"
#include "led.h"
#include "sntp.h"
#include "DIO_Modbus.h"

#ifdef CONFIG_IOT_INTERFACE_TMP
	#include "TMP_sleep.h"
	#include "BLE.h"
	esp_sleep_wakeup_cause_t reason;
	uint8_t bat_mode;
#endif
/// TAG of this module for Debug logs
static const char *TAG = "APP";														
/// If the gateway has problems it will restart after a defined amount of failures
bool rebootloop = true;		

static aio_conf_t aio_conf;														 	
static datalink_t input;

/**
 * @brief Send meta tags on startup
 * 
 * This variable is only used for the temperature gateways.
 * Without this variable the esp will send it's meta tag after every
 * deep sleep caused reboot.
 */
RTC_DATA_ATTR bool meta = true;



/**
 * @brief The main function of the code
 * 
 * Starts all necessary modules for the gateway
 */
void app_main(void)
{
	ESP_LOGD(TAG, "Startup..");
	ESP_LOGD(TAG, "Free memory: %d bytes", esp_get_free_heap_size());
	ESP_LOGD(TAG, "IDF version: %s", esp_get_idf_version());


	ESP_LOGD(TAG, "Configuring Log levels");  											// Set the loging levels for debugging for each module
	esp_log_level_set("*", ESP_LOG_INFO);
	esp_log_level_set("MQTT_CLIENT", ESP_LOG_VERBOSE);
	esp_log_level_set("TRANSPORT_TCP", ESP_LOG_VERBOSE);
	esp_log_level_set("TRANSPORT_SSL", ESP_LOG_VERBOSE);
	esp_log_level_set("TRANSPORT", ESP_LOG_VERBOSE);
	esp_log_level_set("OUTBOX", ESP_LOG_VERBOSE);
	
	esp_log_level_set("APP", ESP_LOG_DEBUG);
	
	esp_log_level_set("MAX31865", ESP_LOG_WARN);
	esp_log_level_set("AIO_Board", ESP_LOG_DEBUG);
	esp_log_level_set("AIO_Conf", ESP_LOG_DEBUG);
	esp_log_level_set("AIO_Netw", ESP_LOG_DEBUG);
	esp_log_level_set("Mqtt", ESP_LOG_DEBUG);
	esp_log_level_set("AIO_Intr", ESP_LOG_INFO);
	esp_log_level_set("AIO_SNTP", ESP_LOG_INFO);
	esp_log_level_set("led",ESP_LOG_INFO);
	esp_log_level_set("cJSON_parse",ESP_LOG_DEBUG);
	esp_log_level_set("DIO_Modbus",ESP_LOG_DEBUG);
	esp_log_level_set("TMP_sleep",ESP_LOG_DEBUG);



	ESP_LOGD(TAG, "Init modules..");
	init_led();														// Init LED
	

	init_CONF(&aio_conf, AIO_CONF_INIT_MEMORY);						// Init Configuration from Memory
	// init_CONF(&aio_conf, AIO_CONF_INIT_CUSTOM);					// Init Configuration from Custom folder. No changes can be made in the configurator
		
	#ifdef CONFIG_IOT_INTERFACE_AIO
	ESP_LOGI(TAG, "AIO SETUP");
	init_AIO (&aio_conf, &input);                                    // Init AIO Board

	
	#elif CONFIG_IOT_INTERFACE_DIO
 	ESP_LOGI(TAG, "DIO SETUP");
	ESP_ERROR_CHECK(init_MODBUS());									// Init Modbus for Digital Board
	init_modbus_devices(&aio_conf, &input);

	#elif CONFIG_IOT_INTERFACE_TMP
	ESP_LOGI(TAG, "TMP SETUP");
	esp_rom_gpio_pad_select_gpio(max_en);
	gpio_set_direction(max_en, GPIO_MODE_OUTPUT);
	gpio_set_level(max_en, 1);
	bat_mode = aio_conf.tmp_bat_mode;
	ESP_LOGD(TAG, "BATmode = %d", bat_mode);

	reason = esp_sleep_get_wakeup_cause();
	ESP_LOGD(TAG, "Wakeupreason: %d",reason );
	if (reason == ESP_SLEEP_WAKEUP_EXT0)
	{
		aio_conf.tmp_bat_mode = 0;
		bat_mode = 0;
		rebootloop = false;
		//input.sleep = 0; 
		// eddy_stone(false);
	}
	init_RTD(&aio_conf, &input);
	ESP_LOGI(TAG, "Batmode" );
	if(bat_mode == 1)
	{
		deep_sleep_tmp(&aio_conf, &input);
	}
	#endif 

	init_INTR();													// Init Interrupts
	init_NETW(&aio_conf, &input);									// Init Network
	#ifdef CONFIG_IOT_INTERFACE_TMP
		if (reason == ESP_SLEEP_WAKEUP_EXT0)
			eddy_stone(true);
	#endif
	init_time();													// Init mutex for sntp time function
	ota(&input);													// Init OTA
	init_MQTT(&aio_conf, &input);									// Init MQTT
	// Set meta Tag on Aedifion server
	if (meta && aio_conf.mqtt_encode == MQTT_ENCODE_AED)
	{
		ESP_LOGI(TAG,"Set Meta Tags");
		meta = false; 
		publish_meta_tag();												// publish Meta tags for Datapoints
	}
	// if (aio_conf.mqtt_autoconfig == 1)
	// {
		
	// }
	led_blink(1);

	#ifdef CONFIG_testmode
	wifi_signal();													// send the signal strength to AP over MQTT
	#endif

    while(1){
		// vTaskDelay(100 / portTICK_PERIOD_MS);
         vTaskDelay(portMAX_DELAY);
		
	}
}

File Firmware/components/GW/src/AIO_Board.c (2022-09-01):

#include "AIO_Board.h"
#include <esp_log.h>
#include <string.h>



uint16_t RTD_REF;
// ---------- Constants

#define PWM_OFFS		0.00720000
#define PWM_GAIN		0.98930000
#define GPIO_ATTN		0.52621507	// GPIO * (R1//R3) / (R2 + R1//R3) = GPIO * (2k2//1k) / (619 + 2k2//1k) = GPIO * GPIO_ATTN
#define VREF_ATTN		0.31250000	// VREF_EXT * 1.0 / (1.0 + 2.2) = VREF_EXT * VREF_ATTN
#define AI_V_ATTN		0.09140969	// Vi = ADC / 2^12 * VREF / (3.32 / (3.32 + 33)) = ADC / 2^12 * VREF / AI_V_ATTN
#define AI_I_ATTN		44.6865752	// Ii = ADC / 2^12 * VREF / (45.3//3300)         = ADC / 2^12 * VREF / AI_I_ATTN
#define AO_V_GAIN		3.15517241	// VOUT = VDAC * (1 + 10 / 4.64) = VDAC * AO_V_GAIN

// ---------- PWM

#define PWM_HS_TIMER	LEDC_TIMER_0
#define PWM_HS_MODE		LEDC_HIGH_SPEED_MODE
#define PWM_HS_CH0_GPIO	PIN_XTR_DAC
#define PWM_HS_CH0_CHAN	LEDC_CHANNEL_0


static const char *TAG = "AIO_Board";

static aio_dev_t AIO;

// ---------- PWM descriptors
static ledc_timer_config_t	 pwm_timer;
static ledc_channel_config_t pwm_channel;


float map_raw(float x, float _in_min, float _in_max, float _out_min, float _out_max)
{
	float m = (_out_max - _out_min) / (_in_max - _in_min);
	float y = (m * (x - _in_min) + _out_min);
	return y;
}

float map(float x, aio_conv_t _type)
{
	float raw = 0.000;
	switch (_type)
	{
	case AI_CODE_TO_VOLT:
		return (AIO.VREF_ADC * x / AIO.AI_code_max);		// V = VREF * CODE / 2^12, V = [0,VREF]
		break;

	case AI_VOLT_TO_PHYS:
		if ((AIO.AI == AIO_VOLTAGE_0_10) || (AIO.AI == AIO_VOLTAGE_2_10))
			return (x * (33 + 15.8) / 15.8);
			// return map_raw(x, 0, AIO.VREF_ADC, 0.0, AIO.VREF_ADC / AI_V_ATTN);
		if ((AIO.AI == AIO_CURRENT_0_20) || (AIO.AI == AIO_CURRENT_4_20))
			return (x / 156.4356*1000); //  divide the reading by the parallel 158 // 15800 that is 156.4356
			// return map_raw(x, 0, AIO.VREF_ADC, 0.0, AIO.VREF_ADC / AI_I_ATTN * 1000.0);
		break;

	case AI_PHYS_TO_UNIT:
		raw = map_raw(x, AIO.AI_phys_min, AIO.AI_phys_max, AIO.AI_unit_min, AIO.AI_unit_max);
		if (raw < AIO.AI_unit_min)
			return AIO.AI_unit_min;
		if (raw > AIO.AI_unit_max)
			return AIO.AI_unit_max;
		return raw;
		break;

	case AO_UNIT_TO_PHYS:
		return map_raw(x, AIO.AO_unit_min, AIO.AO_unit_max, AIO.AO_phys_min, AIO.AO_phys_max);
		break;

	case AO_PHYS_TO_VOLT:
		if ((AIO.AO == AIO_VOLTAGE_0_10) || (AIO.AO == AIO_CURRENT_0_20))
			return map_raw(x, AIO.AO_phys_min, AIO.AO_phys_max, 0.0 / AO_V_GAIN, 10.0 / AO_V_GAIN);
			// return map_raw(x, AIO.AO_phys_min, AIO.AO_phys_max, 0.0 / AO_V_GAIN, 10.0 / AO_V_GAIN);
		if ((AIO.AO == AIO_VOLTAGE_2_10) || (AIO.AO == AIO_CURRENT_4_20))
			return map_raw(x, AIO.AO_phys_min, AIO.AO_phys_max, 2.0 / AO_V_GAIN, 10.0 / AO_V_GAIN);
			// return map_raw(x, AIO.AO_phys_min, AIO.AO_phys_max, 2.0 / AO_V_GAIN, 10.0 / AO_V_GAIN);
		break;

	case AO_VOLT_TO_CODE:
		if ((AIO.AO == AIO_VOLTAGE_0_10) || (AIO.AO == AIO_VOLTAGE_2_10))
			raw = x/(1.0/512.0 *3.3*(1.0+10.0/4.64));		// V = DC/512 x 3.3 x ( 1 + 10 ÷ 4.64  = DC/0.0203360722
			// raw = x/0.020336072198276;
		if ((AIO.AO == AIO_CURRENT_0_20) || (AIO.AO == AIO_CURRENT_4_20))
			raw = x/0.040753651699952;
			// raw = x/(1/512*3.3*(1+10/4.64)/4.99*10)								//for current output is DC/512 x 3.3 x ( 1 + 10 ÷ 4,64 ) /499
		ESP_LOGD(TAG, "DC = %f", raw); 
		return raw;	
		// return (x - PWM_OFFS) * AIO.AO_code_max / AIO.VSUP / PWM_GAIN;		// V = CODE / 2^9 * VSUP * PWMG + PWMO, V = [0,VSUP]
		break;

	default:
		break;
	}

	return 0;
}

void set_raw_channel(uint8_t ch)
{
	pwm_channel.gpio_num = ch;
	ledc_channel_config(&pwm_channel);
}

void set_raw(uint16_t code)
{
	ESP_LOGD(TAG,"Set the value and OD to low, code=%d",code);
	gpio_set_level((gpio_num_t)PIN_XTR_OD, 0);
	ESP_ERROR_CHECK(ledc_set_duty(pwm_channel.speed_mode, pwm_channel.channel, code & 0x01FF));
	ESP_ERROR_CHECK(ledc_update_duty(pwm_channel.speed_mode, pwm_channel.channel));
}

void AIO_set(float _unit)
{	
	ESP_LOGD(TAG, "_unit = %f", _unit);
  
	if (AIO.AO == AIO_DISABLED){
		ESP_LOGD(TAG, "AIO_DISABLED");
		return;
	}
 
	// ESP_LOGD(TAG, "_unit = %f", _unit);
	if (_unit > AIO.AO_unit_max)
		_unit = AIO.AO_unit_max;
	if (_unit < AIO.AO_unit_min)
		_unit = AIO.AO_unit_min;
	ESP_LOGD(TAG, "_unit(fixed) = %f", _unit);
 
	float _phys = map(_unit, AO_UNIT_TO_PHYS);
	// float _volt = map(_phys, AO_PHYS_TO_VOLT);
	float _volt = _phys;
	float _code = map(_volt, AO_VOLT_TO_CODE);

	ESP_LOGD(TAG, "_phys = \t%f", _phys);
	ESP_LOGD(TAG, "_volt = \t%f", _volt);
	ESP_LOGD(TAG, "_code = \t%f", _code);


	 set_raw(_code);
	// set_raw(256);
}

float AIO_get(uint16_t n)
{
	ESP_LOGD(TAG, "AIO_get");
	if (AIO.AI == AIO_DISABLED){
		ESP_LOGD(TAG, "AIO_DISABLED");
		return 65000.000;
	}

	// float _code = get_raw(n);
	float _volt = get_voltage();
	// float _volt = map(_code, AI_CODE_TO_VOLT);
	float _phys = map(_volt, AI_VOLT_TO_PHYS);
	float _unit = map(_phys, AI_PHYS_TO_UNIT);

	return _unit;
}
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

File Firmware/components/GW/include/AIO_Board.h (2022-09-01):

/** @file 
 * @brief The configuration and initialisation of the analog gateway and meanwhile also of the temp gateway
 * 
 * 
 * @date Jan 2021
 * 
*/

#ifndef _AIO_BOARD_H_
#define _AIO_BOARD_H_

#include "freertos/FreeRTOS.h"
#include "freertos/task.h"
#include "freertos/queue.h"
#include "driver/adc.h"
#include "driver/dac.h"
#include "driver/ledc.h"
#include "driver/gpio.h"
#include "TMP_MAX31865.h"
#include "Conf.h"
#include "AIO_MCP3021.h"
#include "led.h"

extern bool rebootloop;
// ---------- GPIO Definitions

/// @todo Move PIN reset to AIO_Conf.h
#define PIN_RESET		 0

// #define PIN_ADC			37	// ADC1_CH1
// #define PIN_DAC			DAC_CHANNEL_2	// 26
// #define PIN_CAL			 4

// XTR111 = Voltage to Current converter
/// XTR Output Disable 	
#define PIN_XTR_OD		26	
/// XTR Output Failure 
#define PIN_XTR_EF		27	
/// XTR Output PWM	
#define PIN_XTR_DAC		25		

// Digital to analog converter = MCP3021
/// DAC Address
#define MCP3021_ADDRESS 0X4d
/// DAC SDA PIN
#define PIN_MCP_SDA		17
/// DAC SCL PIN
#define PIN_MCP_SCL		16


/// @todo Put MAX configuration to seperate Config file for the RTD board. 

// MAX31865 RTD-To digital Converter

/// Chip select PIN for MAX 2
#define PIN_MAX_CS_2	16	// VSPICS0	SPI Chips Select 
/// Chip select PIN for MAX 2
#define PIN_MAX_CS_1	17	
// #define PIN_MAX_RDY		 9	//	SPI Data Ready 		

/// VSPICLK	SPI Clock 
#define PIN_MAX_SCK		5	
/// VSPIQ	SPI MISO 			
#define PIN_MAX_MISO	4		
/// VSPID	SPI Chip Select			
#define PIN_MAX_MOSI	18	



// ---------- AIO Modes
/**
 * @brief The diffrent input and output modes
 */ 
typedef enum {
	AIO_DISABLED = 0,
	AIO_VOLTAGE_0_10,
	AIO_VOLTAGE_2_10,
	AIO_CURRENT_0_20,
	AIO_CURRENT_4_20,
	AIO_PASSIVE
} aio_mode_t;


/**
 * @brief enumeration for the calculation of the output value
 * 
 * This is used for a better overview while using a switch to calculate the input/output value.
 * 
 */ 
typedef enum {
	AI_CODE_TO_VOLT = 0,
	AI_VOLT_TO_PHYS,
	AI_PHYS_TO_UNIT,
	AO_UNIT_TO_PHYS,
	AO_PHYS_TO_VOLT,
	AO_VOLT_TO_CODE
} aio_conv_t;


/**
 * @brief Structure for storing the values during the Calculation
 * 
 * The values from the ADC are converted to the real values. The interim results are stored in this struct.
 * 
 */ 
typedef struct {
	aio_mode_t AI;
	aio_mode_t AO;

	float	AI_unit_max;
	float	AI_unit_min;
	float	AO_unit_max;
	float	AO_unit_min;

	float	AI_phys_max;
	float	AI_phys_min;
	float	AO_phys_max;
	float	AO_phys_min;

	float	AI_code_max;
	float	AI_code_min;
	float	AO_code_max;
	float	AO_code_min;

	uint8_t	OFFS_CAL;
	float	OFFS_ADC;
	float	VREF_EXT;
	float	VREF_ADC;
	float	VSUP;
	float	VSUP1;
} aio_dev_t;

#ifdef __cplusplus
extern "C" {
#endif


/**
 * @brief Function for initialisation of the analog gateway
 * 
 * @param[in] aio_conf
 * @param[in] input
 * 
 * @return ESP_OK if success 
 */ 
esp_err_t init_AIO(aio_conf_t *aio_conf, datalink_t* input);


/// @todo Put to RTD specific config file (init_RTD function)
/**
 * @brief Function for initialisation of the temperature gateway
 * 
 * @param[in] aio_conf
 * @param[in] input
 * 
 * @return ESP_OK if success 
 */ 
esp_err_t init_RTD(aio_conf_t *aio_conf, datalink_t* input);


/**
 * @brief Function for restarting the Gateway
 * 
 * This function cheacks if the interrupt button is pressed. This will disalbe the restart process.
 * Hence, the gateway will not restart if the button is pressed during the configuration of the gateway.
 */ 
void restart_on_failure();

/**
 * @brief This function will set the given voltage as output voltage
 * 
 * The raw value will be calculated from the given value
 * 
 * @param[in] _unit: The voltage which should be set
 */ 
void  AIO_set(float _unit);


/**
 * @brief This Function gets the value from the ADC.
 * 
 * @param[in] n: Deprecated/ @todo delete n
 */ 
float AIO_get(uint16_t n);

/**
 * @brief This function will set the actuator initial value with the last one it had before restart
 */ 
esp_err_t AO_Init();

/**
 * @brief store the last setpoint in nvs 
 */ 

esp_err_t setpoint_save(uint32_t setpoint1,uint32_t setpoint2);

#ifdef __cplusplus
}
#endif //__cplusplus

#endif

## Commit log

2022-09-01 initial push of the data
    [Device-Config_autoconf.xlsx, iot_ai.sch, iot_aio.kicad_pcb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]
2022-09-07 update files for flashing the temperature gw
2022-10-11 Add scripts and data files of the performance analysis
    [gw_costs_calc.xlsx]
